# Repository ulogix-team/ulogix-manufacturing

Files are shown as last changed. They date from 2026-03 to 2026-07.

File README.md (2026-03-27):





<p align="center">
  
</p>

<p align="center">
  
  &nbsp;
  
  &nbsp;
  
  &nbsp;
  
  &nbsp;
  
</p>

# ulogix-manufacturing

Repositorio de ingeniería de proceso, diseño de planta, gemelo digital y automatización de la línea de bebidas FEMSA / Coca-Cola Fontibón.  
Cubre los módulos: **Introducción a la Automatización**, **Celda Robotizada**, **Digital Factory** y **Controladores Industriales**.



## Estructura

```
ulogix-manufacturing/
├── proceso/          DOP, DAP, P&ID, ISA-95, recetas (Líneas 2, 3, 7)
├── planta/           Layout funcional FEMSA, planos 2D, flujo de materiales
├── gemelo-digital/   Digital Factory NX MCD, señales I/O, conexión Logix Emulate
├── nx/               Siemens NX: modelos 3D, exportación RobotStudio→NX
├── studio-5000/      Studio 5000 / Logix Emulate: programas .ACD, tags
├── grafcet/          Control secuencial Grafcet por producto y modo
├── robotstudio/      Celda ABB, simulación, RAPID, análisis de riesgos ISO 10218
└── documentos/       Documentación técnica general y taller de módulo
```



## Líneas de Producción — FEMSA / Coca-Cola Fontibón

| Línea | Producto | Envase | Volumen | Maquinaria principal |
|---|---|---|---|---|
| **Línea 1** | Bebida carbonatada | Vidrio retornable | 330 mL | KRONES Lavatec · HEUFT SX-prewash · KRONES Modulfill HES |
| **Línea 2** | Bebida carbonatada | PET no retornable | 1.5 L | KRONES Contiform Bloc · HEUFT PRIME |
| **Línea 3** | Agua purificada | Garrafón retornable | 25 L | KRONES Hydronomic · HEUFT PRIME |

> Cada producto difiere en envase, velocidad, secuencia Grafcet, inspección y receta — cumpliendo C1 del proyecto integrador.



## Tareas por Módulo

<table>
<tr>
  <td align="center"></td>
  <td>
    <strong>proceso/</strong> — Módulo 1 (Intro Automatización)<br/>
    • Definir arquitectura ISA-95 (Mar 14) — A. Morales<br/>
    • Diagramas P&ID e identificación de sensores/actuadores (Mar 17) — A. Morales<br/>
    • Descripción detallada del proceso productivo (Mar 17) — J. Garzón<br/>
    • Parámetros de proceso y recetas por producto (Mar 18) — J. Díaz / J. Garzón<br/>
    <em>DOP/DAP: L2 (6op+5transp+2insp), L3 (6op+4transp+3insp), L7 (4op+4transp+3insp)</em>
  </td>
</tr>
<tr>
  <td align="center"></td>
  <td>
    <strong>planta/</strong> — Layout funcional<br/>
    • Layout dibujado: J.M. Beltrán (10/03/2026) · Revisado: J.J. Díaz · Aprobado: A.M. Morales<br/>
    • 3 líneas principales + área de jarabes + tratamiento de agua + almacenamiento<br/>
    • L2 y L3 vinculadas al corredor productivo común; L7 con espacio de maniobra para garrafones
  </td>
</tr>
<tr>
  <td align="center"></td>
  <td>
    <strong>robotstudio/</strong> — Módulo 4 (Celda Robotizada)<br/>
    • Justificación y selección del robot industrial (Mar 21) — A. Quenan<br/>
    • Diseño técnico de la celda (Mar 23) — A. Quenan / J. Beltrán<br/>
    • Análisis de riesgos ISO 10218 (Mar 24) — A. Quenan<br/>
    • Simulación en RobotStudio (Apr 11) — A. Quenan<br/>
    • Exportar puntos RS→NX (Apr 18) — A. Quenan / J. Beltrán <em>(sup: S. Sanchez)</em>
  </td>
</tr>
<tr>
  <td align="center"></td>
  <td>
    <strong>nx/</strong> — Módulos 4–5<br/>
    • Modelado 3D de la línea en NX (Mar 25) — J. Beltrán <em>(sup: S. Sanchez)</em><br/>
    • Exportar puntos de RobotStudio a NX (Apr 18) — J. Beltrán <em>(sup: S. Sanchez)</em>
  </td>
</tr>
<tr>
  <td align="center"></td>
  <td>
    <strong>gemelo-digital/</strong> — Módulo 5 (Digital Factory)<br/>
    • Configuración del entorno Digital Factory (Apr 18) — J. Beltrán <em>(sup: S. Sanchez)</em><br/>
    • Virtualización de actuadores y sensores (Apr 22) — A. Morales / J. Beltrán <em>(sup: S. Sanchez)</em><br/>
    • Conexión Logix Emulate – Modelo 3D (Apr 25) — J. Díaz / J. Beltrán <em>(sup: S. Sanchez)</em>
  </td>
</tr>
<tr>
  <td align="center"></td>
  <td>
    <strong>grafcet/ + studio-5000/</strong> — Módulos 4 y 6 (Controladores)<br/>
    • Diseño del Grafcet de control secuencial, por producto y modo (Mar 25) — J. Díaz<br/>
    • Implementación Ladder en Logix Emulate (Apr 22) — J. Díaz<br/>
    • Validación funcional PLC – Gemelo Digital (Apr 29) — J. Díaz / J. Beltrán
  </td>
</tr>
</table>



## Responsables y Supervisiones

| Módulo | Responsable | GitHub | Supervisor de par |
|---|---|:---:|---|
| NX / Digital Factory | Juan Manuel Beltrán Botello | [@JuanBeltran2024](https://github.com/JuanBeltran2024) | **Samuel D. Sanchez** |
| RobotStudio / Celda | Andrés Felipe Quenan Pozo | [@Andres-Felipe-Quenan](https://github.com/Andres-Felipe-Quenan) | Andrés M. Morales |
| Arquitectura ISA-95 / P&ID | Andrés Mauricio Morales Martínez | [@mora200217](https://github.com/mora200217) | Andrés F. Quenan |
| PLC / Grafcet / Ladder | Juan José Díaz Guerrero | [@Judiazgu](https://github.com/Judiazgu) | Juan F. Triana |
| Proceso / VSM / Recetas | Jorge Nicolas Garzón Acevedo | [@Nicolas-Eule](https://github.com/Nicolas-Eule) | Juan M. Beltrán |

**Supervisores académicos:** Carlos J. Cortés · Luis M. Méndez · Víctor H. Grisales · Ricardo Ramírez · Ubaldo García · Eduardo Barrera



## Flujo de Trabajo

```
main ──────────────────► producción estable
  └── develop ─────────► integración y desarrollo
```



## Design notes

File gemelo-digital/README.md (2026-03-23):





# gemelo-digital — Digital Factory



Modelado del gemelo digital con integración de sensores, actuadores virtuales y conexión con Logix Emulate (Módulo 5 — Digital Factory).

## Contenido esperado

- `modelos/` — Archivos de simulación Digital Factory / NX MCD
- `sensores-actuadores/` — Configuración de señales I/O virtuales, mapeo con PLC

## Responsables

| Rol | Nombre | GitHub |
|---|---|:---:|
| Desarrollador principal | Juan Manuel Beltrán Botello | [@JuanBeltran2024](https://github.com/JuanBeltran2024) |
| Integración ISA-95 / Red | Andrés Mauricio Morales Martínez | [@mora200217](https://github.com/mora200217) |
| **Supervisor NX/DF** | **Samuel David Sanchez Cardenas** | [@samsanchezcar](https://github.com/samsanchezcar) |



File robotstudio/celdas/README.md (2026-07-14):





# Sistema Gantry Cartesiano XZ


Esta celda automatiza el paletizado alternado de dos productos distintos —cajones de botellas retornables de 330 ml y paquetes termoformados PET de 1.5 L— mediante un sistema gantry de diseño propio, con dos ejes cartesianos: un eje X de 5 m sobre perfil Bosch Rexroth de correa dentada (motor ABB MU 200 + reductor planetario Apex Dynamics 5:1), y un eje Z de 2.3 m sobre husillo de bolas Bosch Rexroth 40x10 (motor ABB MU 300, acoplado directo sin reductor). Ambos ejes se controlan como ejes externos desde un controlador ABB IRC5, aprovechando motores ABB para mantener compatibilidad de programación con el resto de la línea.
El efector final es un gripper neumático de 4 mordazas (2 cilindros Festo DSBC-80-150 por mordaza), que sujeta cada capa completa de pallet por fricción lateral —hasta ~260 kg en el caso más pesado— y la traslada hasta uno de los dos pallets de destino según el tipo de producto detectado en la banda de infeed. El circuito neumático incluye válvulas de retención pilotada en cada cilindro para prevenir la caída de la carga ante una eventual pérdida de presión en tránsito.
La celda cuenta con vallado perimetral, puerta con enclavamiento, y cortinas de luz con muting en los dos puntos de interfaz con las bandas transportadoras (2 outfeed).

<p align="center">
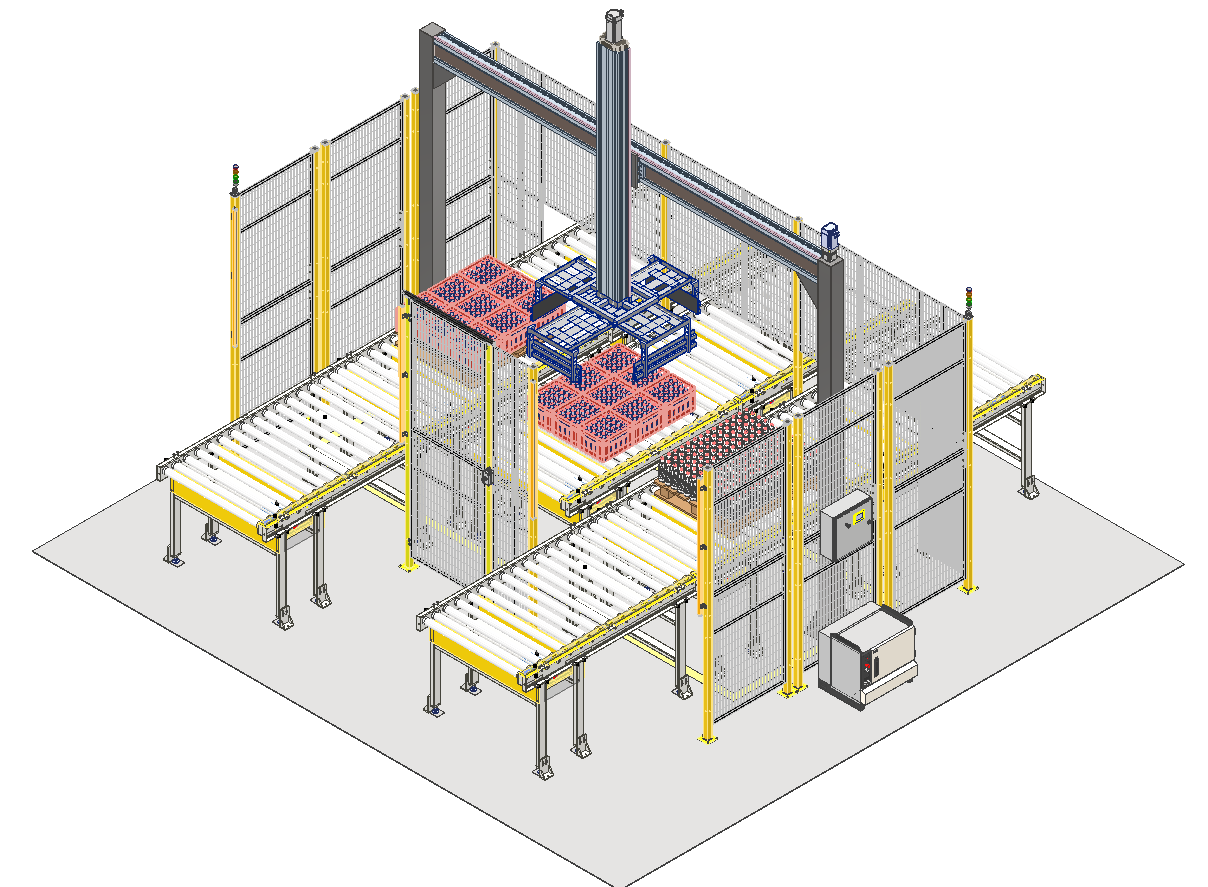
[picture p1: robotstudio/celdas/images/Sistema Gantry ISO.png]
Sistema Gantry
  
</p>

## Diseño

### 1. Función y proceso
Paletizado automático alternado de dos productos: capas de cajones retornables de 330 ml (9 cajones/capa, 6 capas/pallet) y capas de paquetes termoformados PET de 1.5 L (28 paquetes/capa, 5 capas/pallet). El sistema recibe el producto por una banda de infeed que alterna capa a capa entre ambos tipos, y lo distribuye hacia dos líneas de outfeed independientes según el producto detectado.
El archivo de modelado cad se encuentra disponible en [Celda1](cad/Celda1.zip)

### 2. Estructura mecánica y ejes de movimiento
| **Elemento** | **Especificación** |
|---|---|
| Configuración | Gantry cartesiano de 2 ejes (X horizontal, Z vertical), soportado sobre 2 pilares |
| Eje X | Perfil Bosch Rexroth de correa dentada, 5 m de recorrido |
| Motor eje X | ABB MU 200 + reductor planetario Apex Dynamics 5:1 |
| Eje Z | Husillo de bolas Bosch Rexroth 40x10, 2.3 m de recorrido |
| Motor eje Z | ABB MU 300, acoplado directo (sin reductor) |
| Controlador | ABB IRC5 (ejes gestionados como ejes externos) |
| Carga de diseño verificada | 300 kg sobre el eje Z — validado con margen (~46% en aceleración, ~58% en sostenimiento) bajo Trms del MU300 con *lead* de husillo de 10 mm |

### 3. Efector final (gripper)
- 4 mordazas neumáticas, accionamiento por fricción lateral sobre la capa de pallet
- 2 cilindros Festo DSBC-80-150-PPSA-N3 por mordaza (8 en total), diámetro dimensionado para el caso crítico (paquetes 1.5 L, ~260 kg, μ≈0.35 poliuretano-LDPE)
- Cuerpo del gripper: pieza manufacturada en aluminio 6061-T6

### 4. Sistema Neumático
| **Función** | **Componente** |
|---|---|
| Retención de carga ante pérdida de presión | 8x válvulas de retención pilotada Festo HGL-3/8 (una por cilindro) |
| Actuación direccional | Electroválvula Festo VUVS-L30 (5/2, doble solenoide) |
| Control de velocidad de cierre | Reguladores de caudal unidireccionales Festo GRLA-3/8 |
| Ajuste de fuerza de apriete por producto | Regulador de presión proporcional Festo VPPM-6L |
| Acondicionamiento de aire | FRL Festo MS4-LFR-1/4 |
| Retroalimentación de posición | Sensores magnéticos Festo SMT-8M-A (2 por mordaza) |

### 5. Transporte de material
- 8x bandas motorizadas Interroll PM 9710 (infeed + 2 líneas de outfeed)
- 3x sensores fotoeléctricos retroreflectivos con filtro de polarización Pepperl+Fuchs OBR7500, para detección confiable de cajones y envoltura PET transparente (1 infeed, 2 outfeed)

### 6. Sistema eléctrico
| **Función** | **Componente** |
|---|---|
| Alimentación IRC5 (motores MU200/MU300) | Breaker ABB S203-K25 + RCD tipo B ABB F204B |
| Circuito de control 24VDC | Fuente ABB CP-E 24/10.0 |
| Cargas individuales de 24VDC (HMI, interlock, cortinas, torres) | Mini-breakers ABB S201-C1 |
| Gabinete | Schneider NSYCRN75250, IP66 |
| Interfaz operador | HMI ABB CP620 |

### 7. Seguridad
- Vallado perimetral modular Satech ImpactGuard (malla 20×100 mm, absorción de impacto 2200 J)
- Puerta de acceso con enclavamiento Schmersal AZM 415
- 2x cortinas de luz ReeR Admiral AD 1651 (Tipo 4 / PL e) con interfaz de muting SR ONE M, en infeed y outfeed
- 2x paros de emergencia (EAO Serie 45 en puerta, EAO Serie 84 Smart-Box en HMI)
- 2x torres de señalización Werma KS72
- Freno electromagnético integrado en el motor MU 300 (retención de posición vertical)

## Resumen de costos

**Total estimado: ~US$108,143**

| Categoría | Peso aproximado en el total |
|---|---|
| Transportadores (8x Interroll PM 9710) | ~41% — el ítem dominante en esta celda |
| Controlador + servomotores (IRC5 + MU300 + MU200) | ~21% |
| Estructura mecánica (ejes lineales Bosch Rexroth, perfiles, gripper manufacturado) | ~24% |
| Seguridad (vallado, cortinas, interlock, paros, torres) | ~5% |
| Sistema neumático (cilindros, válvulas, VPPM) | ~3% |
| Protecciones eléctricas, tablero y HMI | ~1% |

**Nivel de confianza**: bajo para IRC5+servomotores y ejes lineales Bosch Rexroth (configuración no estándar, sin precio público); medio para el gripper y estructura manufacturada (estimación de costo de material + maquinado). Alto para componentes de catálogo (Festo, ABB, sensores Pepperl+Fuchs).  

El BOM se encuentra disponible en [BOM1](BOM/BOM1.xlsx)

# Manipulador Articulado ABB IRB 5710


Esta celda automatiza el paletizado de garrafones de 25 litros de agua mediante un robot articulado de 6 ejes ABB IRB 5710 (variante 110 kg / 2.3 m de alcance), controlado por un OmniCore V250XT. El robot recibe los garrafones desde una banda transportadora de infeed y los deposita sobre un pallet con rack metálico, formando unidades de 5 capas × 6 posiciones.
El efector final es un gripper neumático de 3 ventosas tipo fuelle, cada una con su propio circuito de vacío independiente (generador Festo OVEM con válvula anti-retorno y sensor de vacío integrado), lo que permite levantar 3 garrafones por ciclo (~90 kg de carga total incluyendo el gripper) y detectar de forma individual si alguno de los tres no fue sujetado correctamente. El pallet completo se evacúa mediante un tramo de bandas motorizadas Interroll PM 9710.
La celda está delimitada por un perímetro de seguridad con vallado modular, puerta de acceso con enclavamiento, y cortinas de luz con función de muting en los puntos de infeed y outfeed, permitiendo el paso automático de material sin exponer al personal a la zona de riesgo del robot.

<p align="center">
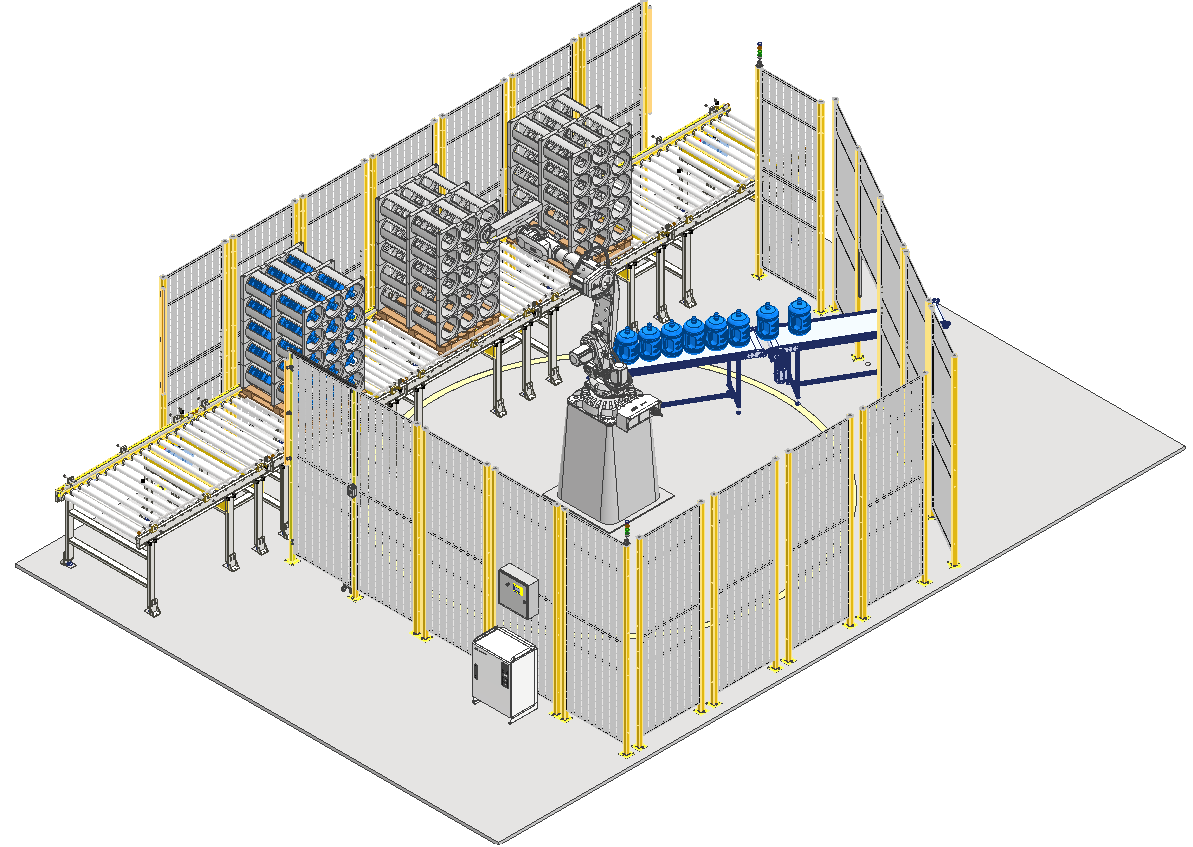
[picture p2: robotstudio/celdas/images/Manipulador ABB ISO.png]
Manipulador ABB
  
</p>

## Diseño

### 1. Función y proceso

Paletizado automático de garrafones de 25 litros de agua. El robot recibe los garrafones desde una banda transportadora de infeed y los deposita sobre un pallet con rack metálico, formando unidades de 5 capas × 6 posiciones. El robot manipula 3 garrafones por ciclo mediante un gripper de vacío de 3 ventosas.
El archivo de modelado cad se encuentra disponible en [Celda2](cad/Celda2.7z)

### 2. Estructura mecánica

| Elemento | Especificación |
|---|---|
| Robot | ABB IRB 5710-110/2.3 (110 kg de carga, 2.3 m de alcance) |
| Controlador | ABB OmniCore V250XT |
| Software de programación | RobotStudio, RobotWare 7.2 |
| Carga manipulada por ciclo | 3 garrafones + gripper ≈ 90 kg (dentro de la capacidad de 110 kg del robot) |
| Configuración de pallet | 5 capas × 6 posiciones sobre rack metálico |

### 3. Efector final (gripper)

- 3 ventosas neumáticas tipo fuelle (2.5 pliegues), diámetro ~180-200 mm
- Punto de contacto: tapa y hombro del garrafón, hasta casi el cuerpo (~270 mm de diámetro disponible)
- Nivel de vacío de trabajo objetivo: -0.30 bar (dimensionado para minimizar tiempo de ciclo con la superficie de contacto disponible)
- 3 circuitos de vacío completamente independientes (uno por ventosa), para detección individual de fallo de sujeción por garrafón

### 4. Sistema neumático (circuito de vacío)

| Función | Componente | Cantidad |
|---|---|---|
| Generación de vacío (alto caudal, válvula y sensor integrados) | Festo OVEM-14-L-B-QO-CE-N-1P | 3 (uno por ventosa) |
| Filtro de vacío (cuerpo transparente, inspección visual) | Festo VAF-PK-6 | 3 |
| Acumulador de vacío (punto de uso, liviano para no afectar el payload) | Festo CRVZS-0.1 (combinable en paralelo si se requiere más volumen) | 3 |
| Acondicionamiento de aire de entrada | Festo MS4-LFR-1/4-D6-C-P-M-AG-BAR-B | 1 (centralizado) |

### 5. Transporte de material

- 5x bandas motorizadas Interroll PM 9710 en la salida de pallets (outfeed), capacidad muy por encima de la carga real (~800-850 kg por pallet)

### 6. Sistema eléctrico

| Circuito | Protección |
|---|---|
| Alimentación OmniCore V250XT (robot + drives) | Breaker ABB S203-K32 (3×32 A) + RCD tipo B ABB F204B |
| Circuito de control 24VDC | Fuente ABB CP-E 24/10.0 |
| Cargas individuales de 24VDC (HMI, puerta, torres, cortinas/interfaces) | 7x mini-breakers ABB S201-C1 |
| Gabinete | Schneider NSYCRN75250, IP66 |
| Interfaz operador | HMI ABB CP620 |

### 7. Seguridad

- Vallado perimetral modular Satech ImpactGuard (malla 20×100 mm, absorción de impacto 2200 J), radio de riesgo calculado a partir del alcance del robot (2.3 m) + gripper + garrafón en la postura más desfavorable
- Puerta de acceso con enclavamiento Schmersal AZM 415
- 2x cortinas de luz ReeR Admiral AD 1501 con interfaz de muting SR ONE M, en infeed y outfeed
- 1x cortina de control de acceso ReeR Admiral AD 2B con interfaz SR ONE (sin muting)
- 2x paros de emergencia (EAO Serie 45, 2NC, en puerta; EAO Serie 84 Smart-Box en HMI)
- 2x torres de señalización Werma KS72
- Avisos de advertencia normalizados: tipo "peligro" en la puerta de acceso, tipo "atención" en las zonas de muting

## Resumen de costos

**Total estimado: ~US$132,046**

| Categoría | Peso aproximado en el total |
|---|---|
| Robot + controlador (IRB 5710 + OmniCore V250XT) | ~66% del total — el ítem dominante |
| Transportadores (5x Interroll PM 9710) | ~21% |
| Gripper + sistema neumático de vacío | ~4% |
| Seguridad (vallado, cortinas, interlock, paros, torres) | ~4% |
| Protecciones eléctricas y tablero | ~1% |
| HMI y otros | ~1% |

**Nivel de confianza**: bajo para robot, controlador y transportadores (ABB e Interroll no publican precio, se cotiza por proyecto — estimado con base en rangos de mercado comparables). Alto para componentes de catálogo estándar (Festo, ABB protecciones, ReeR, EAO, Werma).

El BOM se encuentra disponible en [BOM2](BOM/BOM2.xlsx)



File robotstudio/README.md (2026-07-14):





# Justificación



El análisis de los mapas de flujo de valor (Value Stream Mapping, VSM) permitió identificar que la operación de paletizado constituye el principal cuello de botella en las tres líneas de producción de la planta. Esta etapa presenta los mayores tiempos de ciclo y los menores niveles de disponibilidad respecto a las demás operaciones, ocasionando acumulación de producto antes del final de la línea, incremento del trabajo en proceso y pérdidas de productividad asociadas a tiempos de espera.  
Debido a que el proceso de paletizado se realiza de manera manual, su capacidad depende directamente del desempeño del operario, siendo susceptible a variaciones ocasionadas por fatiga, pausas operativas, diferencias en el ritmo de trabajo y limitaciones ergonómicas propias de la manipulación repetitiva de cargas. Como consecuencia, la velocidad de evacuación del producto terminado resulta inferior a la capacidad de producción de las etapas anteriores, generando saturación en la entrada del paletizado y reduciendo la continuidad del flujo productivo.

# Propuesta



Con el propósito de eliminar esta restricción de capacidad, se propone la implementación de celdas robotizadas de paletizado. La solución contempla una celda compartida para las líneas 1 y 2, debido a que ambas poseen altas velocidades de producción y características similares de empaque, y una segunda celda dedicada para la línea 3, correspondiente al proceso de garrafones, cuyas dimensiones, peso y configuración de carga requieren una solución específica.

La incorporación de manipuladores industriales permite ejecutar el proceso de paletizado con tiempos de ciclo constantes, alta repetibilidad y operación continua, eliminando las variaciones inherentes al proceso manual. De esta manera, la capacidad del sistema de paletizado supera la demanda de producción de las líneas, evitando la acumulación de producto previo a esta estación y permitiendo mantener un flujo continuo hasta el despacho del producto terminado.

# Celdas de paletizado



Las celdas de paletizado se diseñaron teniendo en cuenta factores como tipo de producto, tipo de empaque (encajonado, termoformado, racks), disposición del producto en el pallet, carga por ciclo y tiempo para producir la cantidad de unidades que se operan en un ciclo. Los diseños fueron elegidos para optimizar la etapa de paletizado y mejorar su eficiencia reduciendo los tiempos de ciclo.

## Línea 1 y Línea 2
La organización en los pallets es similar en los dos productos:  
En la línea 1 de botellas retornables de 330 ml los pallets están conformados por 6 capas de 9 cajones organizados en una matriz 3x3 con 30 botellas en cada uno.  
En la línea 2 de botellas PET de 1.5 l los pallets están conformados por 5 capas de 28 paquetes termoformados organizados en una matriz 7x4 con 6 botellas cada uno.  
De acuerdo a referencias de celdas robóticas de paletizado existentes. La duración de un ciclo (tiempo que tarda el mecanismo en tomar la carga llevarla a su destino y devolverse para tomar una nueva carga) es de aproximadamente entre 10 y 15 segundos, considerando que el tacktime de la línea 1 es de 0.1 segundos, al mover 3 cajones por ciclo (90 botellas) se encuentra un tiempo disponible de 9 segundos que resulta insuficiente para la operación, por lo tanto, se optó por mover una capa de pallet en cada ciclo (270 botellas) con un tiempo disponible de 27 segundos, suficiente para realizar el ciclo de forma segura. Por otro lado para mantener el mecanismo de sujeción compatible en dimensiones con el producto de la línea 2 (tacktime de 0.252 segundos) se optó tambíen por mover una capa de pallet (168 botellas) que resulta en un tiempo disponible por ciclo de 42.2 segundos.  
La organización de las capas en los pallets se hace de forma vertical y el transporte entre bandas las capas se hace de forma horizontal, por lo tanto, es necesario un sistema robótico tipo gantry que realice el paletizado de los dos productos y resulta suficiente un mecanismo de 2 ejes para relizar los ciclos de movimiento.

## Línea 3
En la línea 3 de garrafones de 25 l los pallets están conformados por 5 capas de racks organizados en una matriz 3x2, es decir, 6 garrafones en cada capa.  
Considerando un tacktime de 5 segundos, al mover en cada ciclo 3 unidades se tiene un tiempo disponible de 15 segundos, suficiente para un ciclo de operación, por otro lado, la organización del producto en los racks se realiza de forma lateral y la sujeción de forma vertical, es necesario un manipulador de 6 ejes para total libertad de movimiento en la organización del pallet.

## Contenido

- `celdas/` — Diseño de la celda: layout, alcance, seguridad, periféricos
- `programas-rapid/` — Código RAPID de las rutinas del robot
- `analisis-riesgos/` — Evaluación de riesgos y medidas de mitigación (ISO 10218)

## Responsable

Andrés Felipe Quenan Pozo · [@Andres-Felipe-Quenan](https://github.com/Andres-Felipe-Quenan)



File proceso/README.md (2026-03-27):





# proceso — Análisis del Proceso Productivo



Análisis del proceso de fabricación y despacho en la planta de bebidas FEMSA / Coca-Cola Fontibón, desde la recepción de insumos hasta el empaque y despacho. Desarrollado en el marco del **Módulo 1 — Introducción a la Automatización** del curso APM 2026-1.

## Líneas de Producción

| Línea | Producto | Envase | Volumen | Criterio de diferenciación |
|---|---|---|---|---|
| **Línea 1** | Bebida carbonatada | Vidrio retornable | 330 mL | Recepción retornable, lavado, saneamiento, inspección botella vacía (HEUFT SPECTRUM II SX-prewash), etiquetado, llenado (KRONES Modulfill HES), tapado |
| **Línea 2** | Bebida volumen medio | PET no retornable | 1.5 L | Cambio de familia de envase, soplado integrado (KRONES Contiform Bloc), llenado-cierre-etiquetado con diferencias en capacidad vs. línea retornable |
| **Línea 3** | Agua purificada | Garrafón retornable | 25 L | Gran volumen individual, tratamiento agua (KRONES Hydronomic), mayor exigencia sanitaria, tiempos unitarios mayores, logística diferenciada |

> Los tres productos cumplen el criterio C1 del proyecto integrador: diferencias en envase/geometría, velocidad de producción, secuencia lógica, inspección y recetas.



## Maquinaria de Referencia (Benchmark Industrial)

| Equipo | Fabricante | Función | Línea |
|---|---|---|---|
| Lavatec D / LavaClassic D | KRONES | Lavado de botellas retornables | L1 |
| HEUFT SPECTRUM II SX-prewash | HEUFT | Inspección y rechazo de retornables defectuosos antes del llenado | L1 |
| Modulfill HES | KRONES | Llenado higiénico bebidas carbonatadas en vidrio | L2 |
| Contiform Bloc | KRONES | Soplado + llenado integrado para envases PET hasta 3.5 L | L2 |
| Hydronomic | KRONES | Tratamiento y preparación de agua de proceso | L3 |
| HEUFT PRIME | HEUFT | Inspección envases llenos (fisicoquímica en línea) | L1, L2, L3 |

> Estas referencias se usan como benchmark técnico, no como confirmación del inventario exacto de la planta FEMSA visitada.



## DTP — Diagrama de Transformación de Producto

### Línea 1 — Vidrio retornable 330 mL

<p align="center">
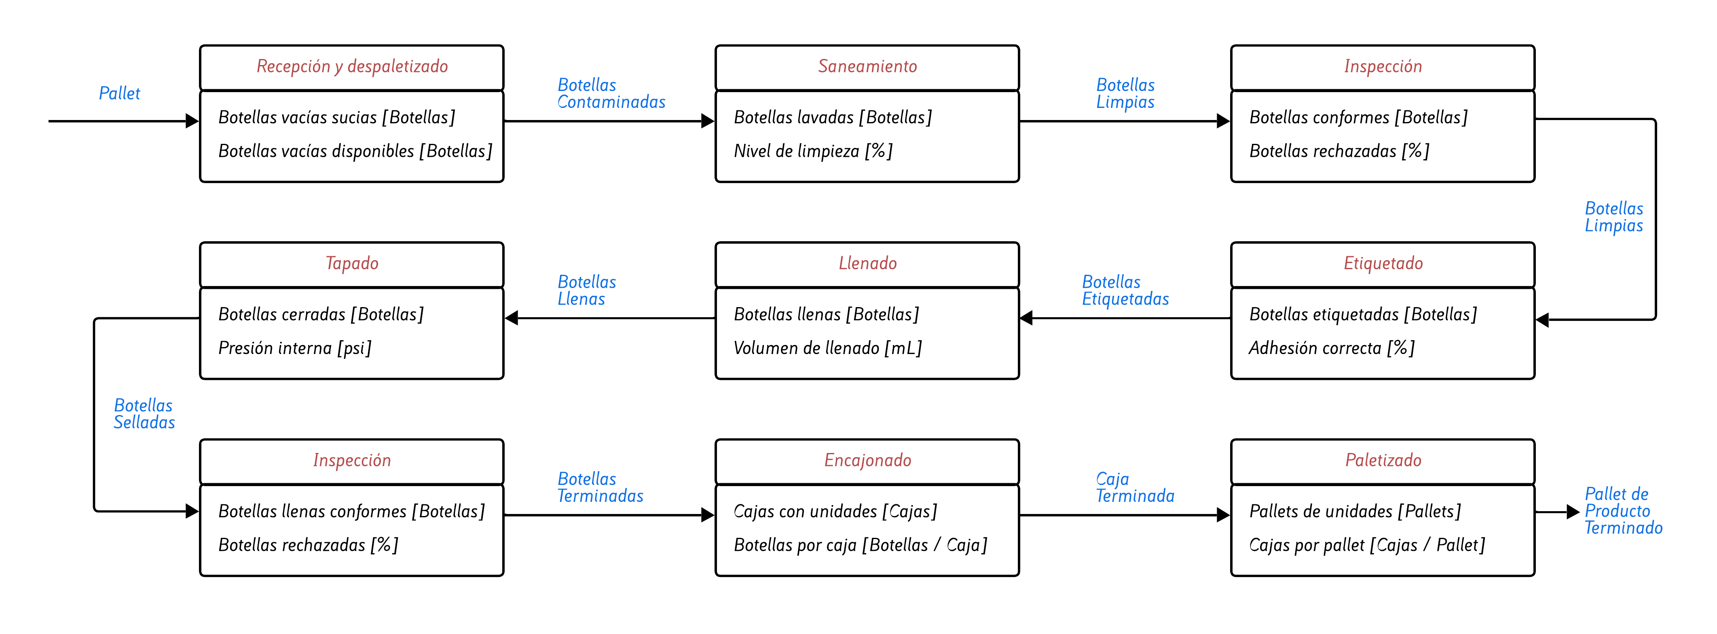
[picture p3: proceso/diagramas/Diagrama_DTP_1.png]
DTP_Linea_1
  
</p>

### Línea 2 — PET 1.5 L

<p align="center">
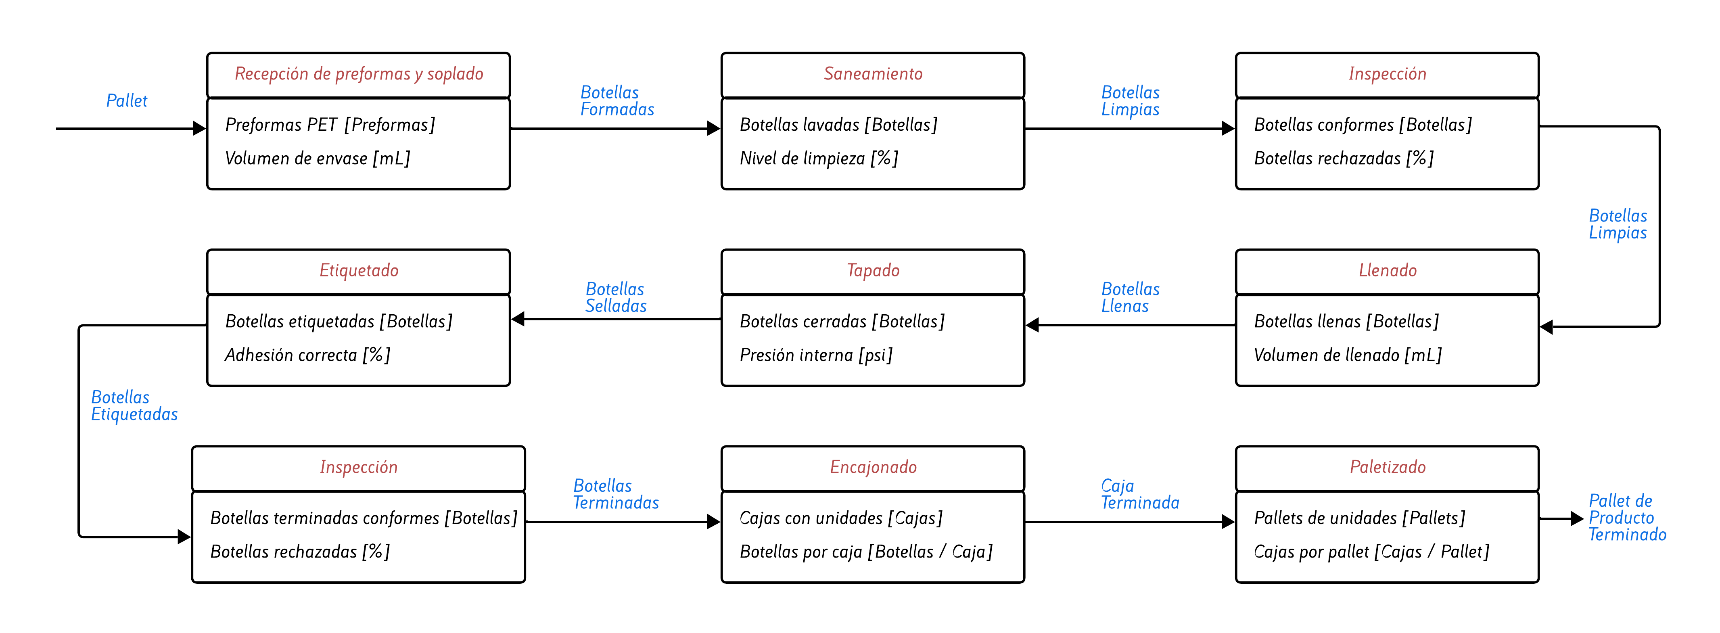
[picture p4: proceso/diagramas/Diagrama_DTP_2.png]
DTP_Linea_2
  
</p>

### Línea 3 — Garrafón 20 L

<p align="center">
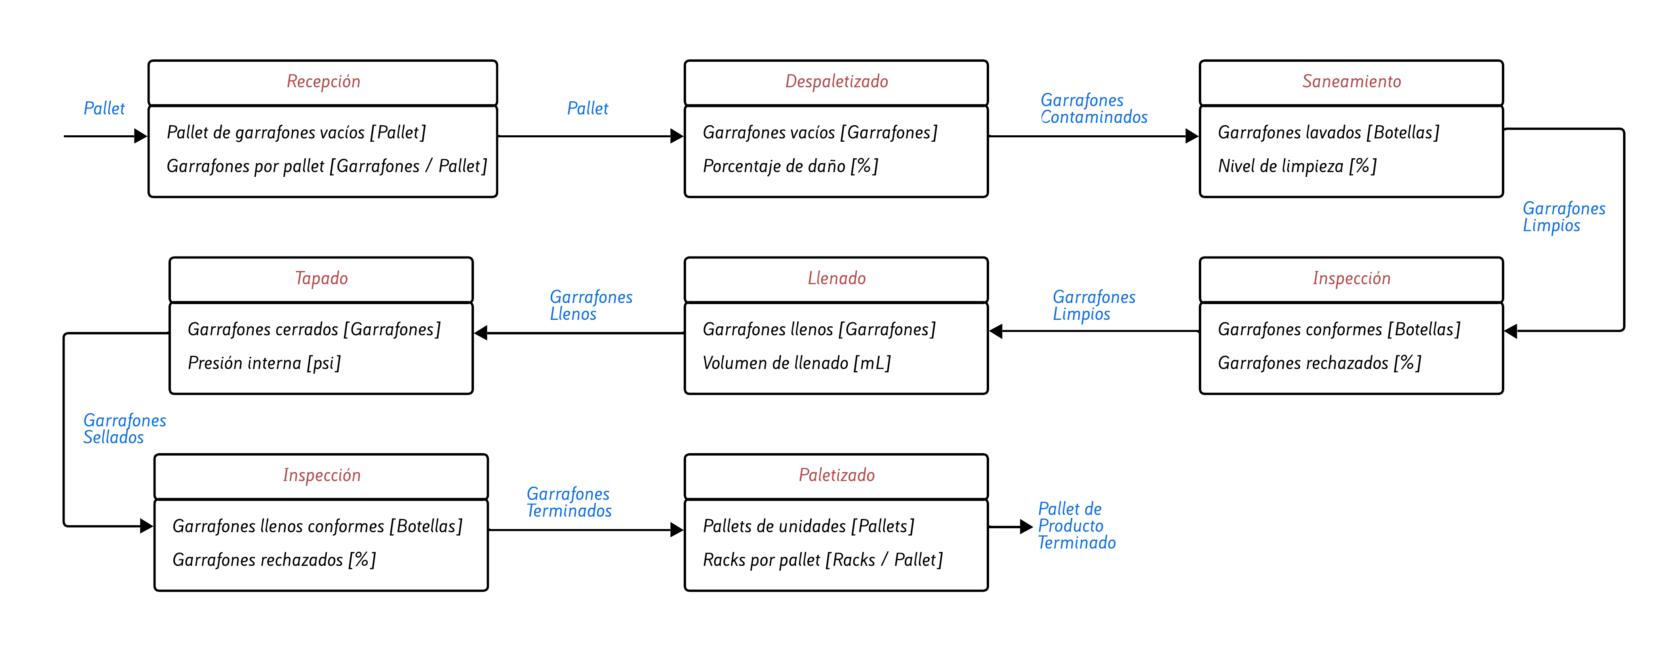
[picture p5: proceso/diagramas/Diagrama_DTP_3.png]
DTP_Linea_3
  
</p>

Los diagramas de transformación evidencian que las variables críticas del proceso se concentran en saneamiento (nivel de limpieza), llenado (volumen en mL), tapado (presión interna) y etiquetado (adhesión). Estas variables influyen directamente en la calidad del producto final, pero también en la velocidad de producción, ya que requieren control preciso y pueden generar rechazos. Se identifica que el llenado es una etapa sensible debido a la necesidad de mantener exactitud volumétrica y presión adecuada en bebidas gaseosas, lo cual puede reducir la disponibilidad efectiva del equipo por ajustes o mantenimiento. Asimismo, el proceso final de encajonado y paletizado representa una transformación logística que impacta significativamente el throughput total de la línea, especialmente al realizarse manualmente.

## DOP — Diagrama de Operaciones de Proceso

### Línea 1 — Vidrio retornable 330 mL

<p align="center">
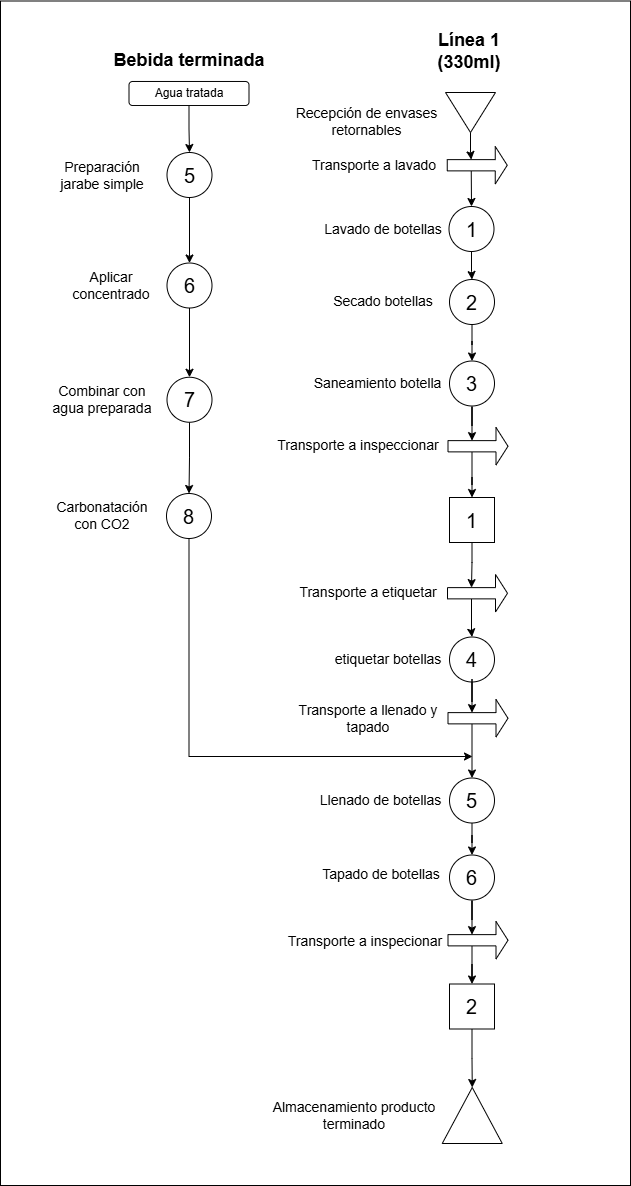
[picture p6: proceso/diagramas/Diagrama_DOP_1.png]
DOP_Linea_1
  
</p>

### Línea 2 — PET 1.5 L

<p align="center">
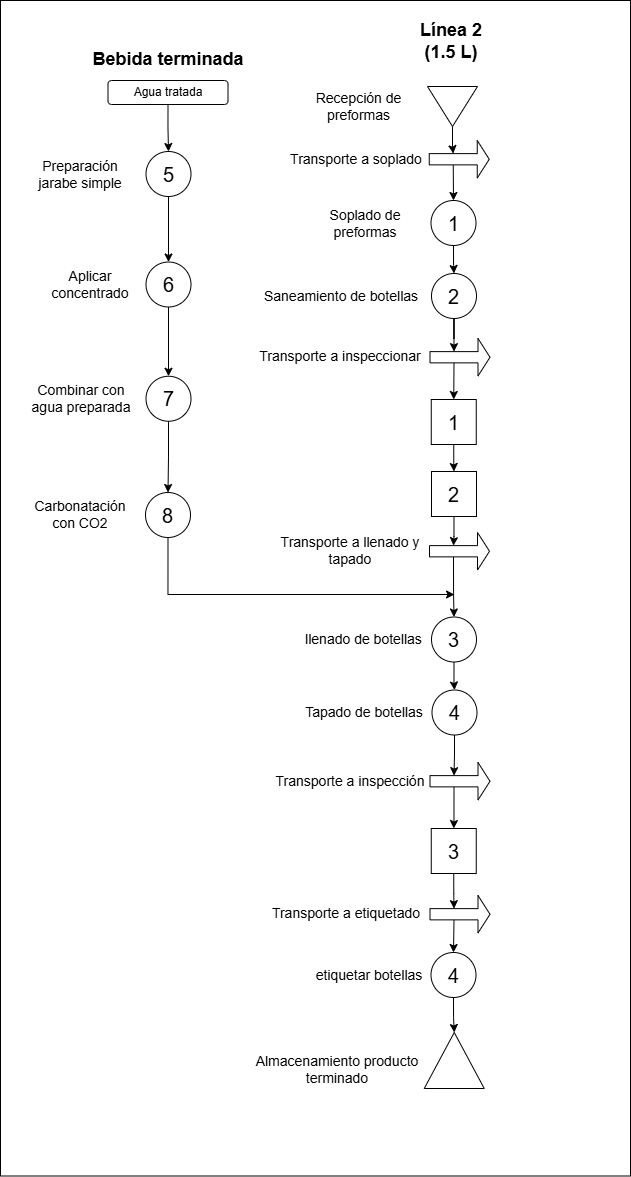
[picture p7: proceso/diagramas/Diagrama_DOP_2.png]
DOP_Linea_2
  
</p>

### Línea 3 — Garrafón 20 L

<p align="center">
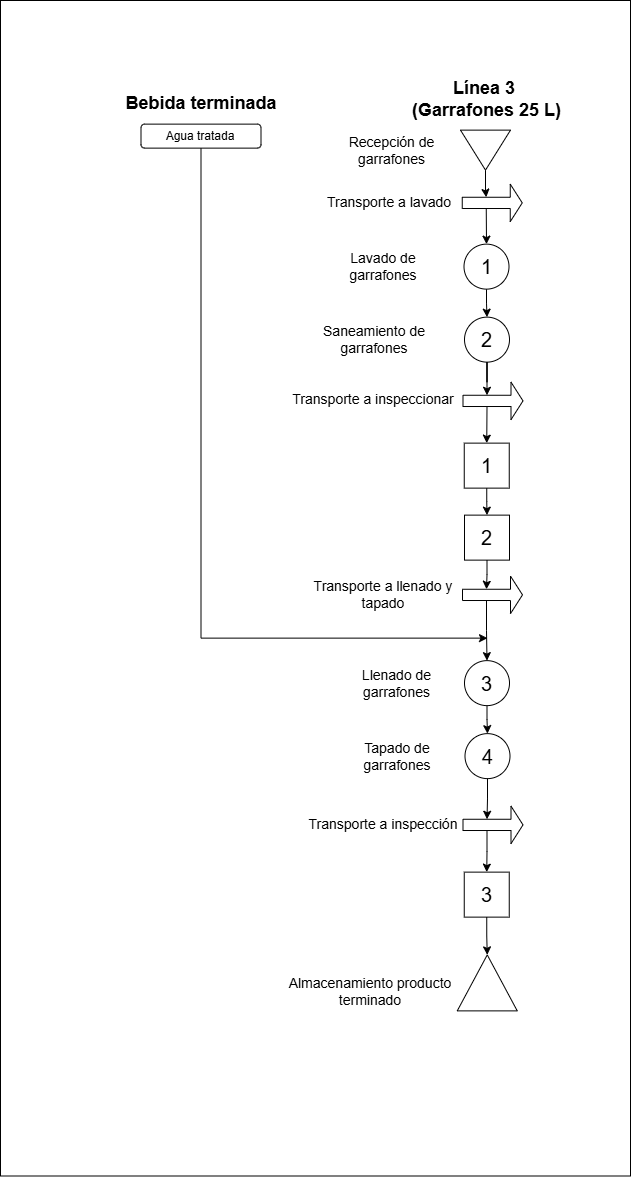
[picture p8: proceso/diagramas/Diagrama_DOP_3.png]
DOP_Linea_3
  
</p>

Los diagramas de operaciones de proceso muestran una secuencia lineal de operaciones con múltiples etapas de transporte entre procesos de lavado, saneamiento, inspección, llenado y tapado. El almacenamiento final sugiere que la capacidad de salida del sistema puede verse limitada por operaciones posteriores, lo cual es consistente con la necesidad de mejorar la automatización en la etapa de manipulación del producto terminado.



## DAP — Diagrama de Análisis de Proceso

### Línea 1 — Vidrio retornable 330 mL

<p align="center">
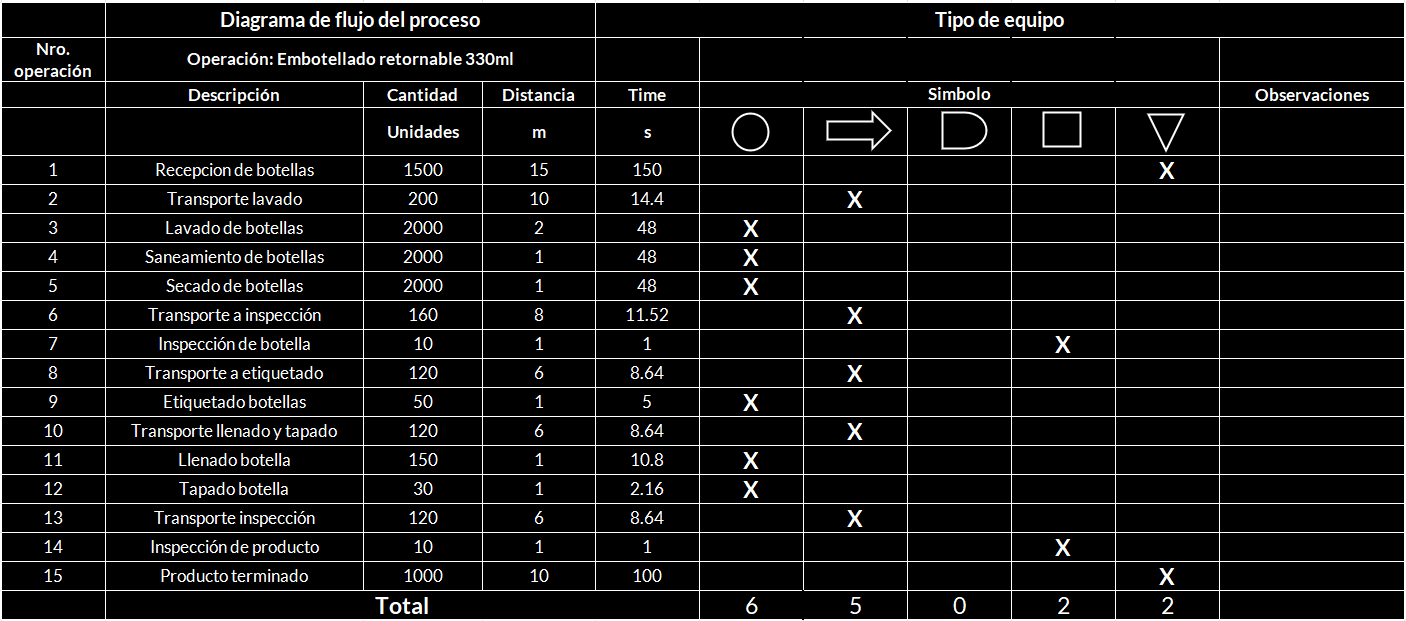
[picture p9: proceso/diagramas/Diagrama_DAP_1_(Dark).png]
DAP_Linea_1
  
</p>

### Línea 2 — PET 1.5 L

<p align="center">
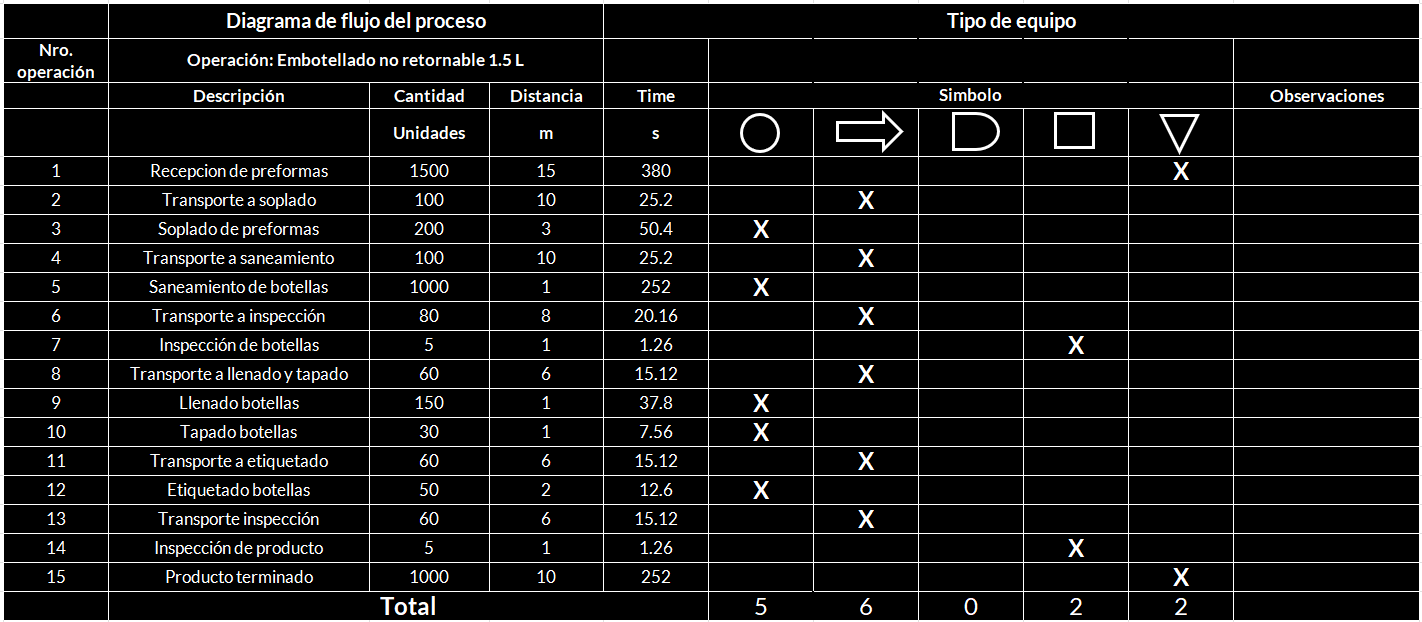
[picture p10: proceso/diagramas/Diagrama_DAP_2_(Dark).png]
DAP_Linea_2
  
</p>

### Línea 3 — Garrafón 20 L

<p align="center">
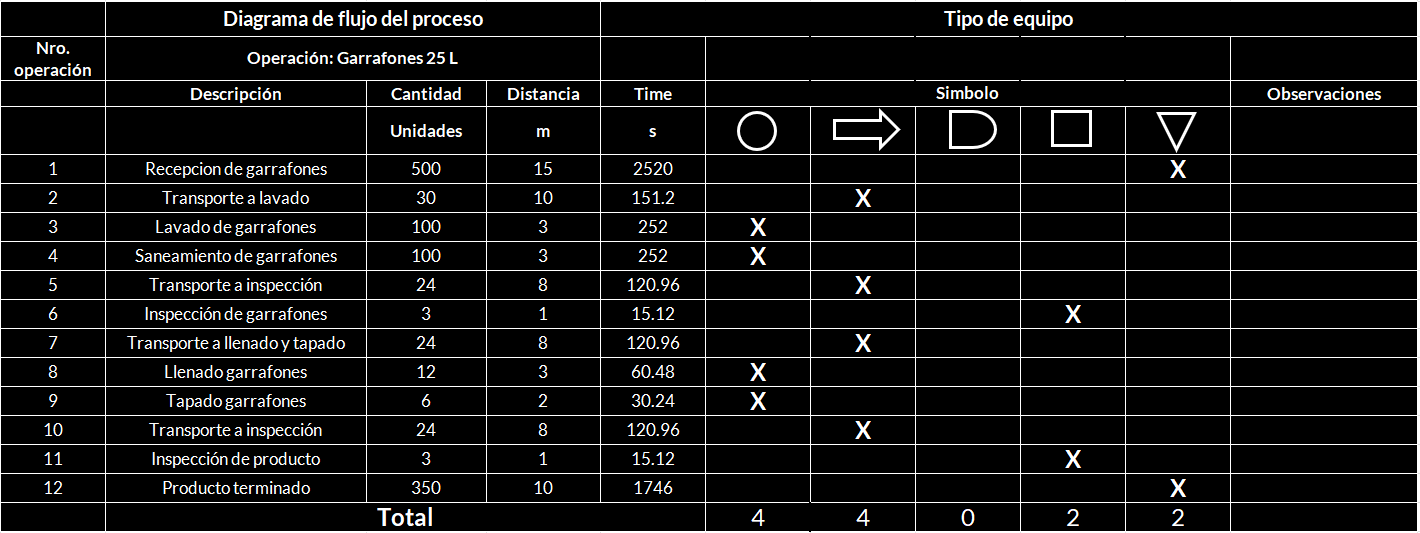
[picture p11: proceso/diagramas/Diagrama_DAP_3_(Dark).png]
DAP_Linea_3
  
</p>

### Resumen Diagrama de Análisis de Proceso
| Línea | Operaciones | Transportes | Demoras | Inspecciones | Almacenamientos | Total |
|---|---|---|---|---|---|---|
| Línea 1 — 330 mL retornable | 6 | 5 | 0 | 2 | 2 | **15** |
| Línea 2 — PET 1.5 L | 5 | 6 | 0 | 2 | 2 | **15** |
| Línea 3 — Garrafón 25 L | 4 | 4 | 0 | 2 | 2 | **12** |

Los diagramas de análisis de proceso evidencian que una proporción significativa de las actividades corresponde a transporte (6) e inspección (2), mientras que solo 5 corresponden a operaciones que agregan valor directo al producto. Esto indica un potencial de mejora en la reducción de movimientos innecesarios mediante mejor distribución de planta o automatización del manejo de materiales. El tiempo más alto se observa en saneamiento de botellas y en la recepción de preformas, mientras que el llenado presenta un tiempo considerable en relación con otras operaciones productivas. La presencia de múltiples transportes intermedios incrementa el lead time total del proceso y sugiere que la eficiencia global puede incrementarse mediante integración de equipos o automatización del flujo entre estaciones.



## VSM - Mapa de Flujo de Valor

### Línea 1 — Vidrio retornable 330 mL

<p align="center">
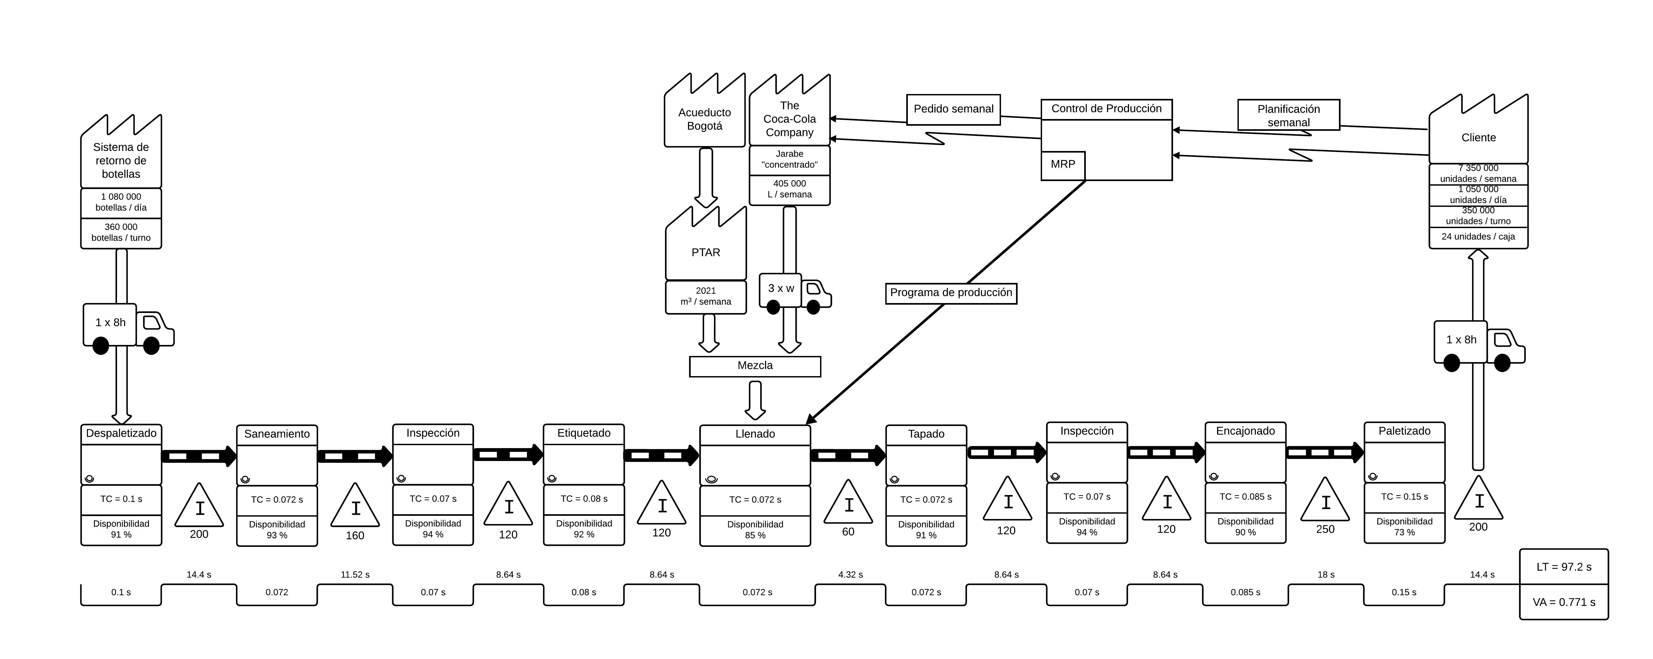
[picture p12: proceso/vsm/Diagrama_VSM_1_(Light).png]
VSM_Linea_1
  
</p>

### Línea 2 — PET 1.5 L

<p align="center">
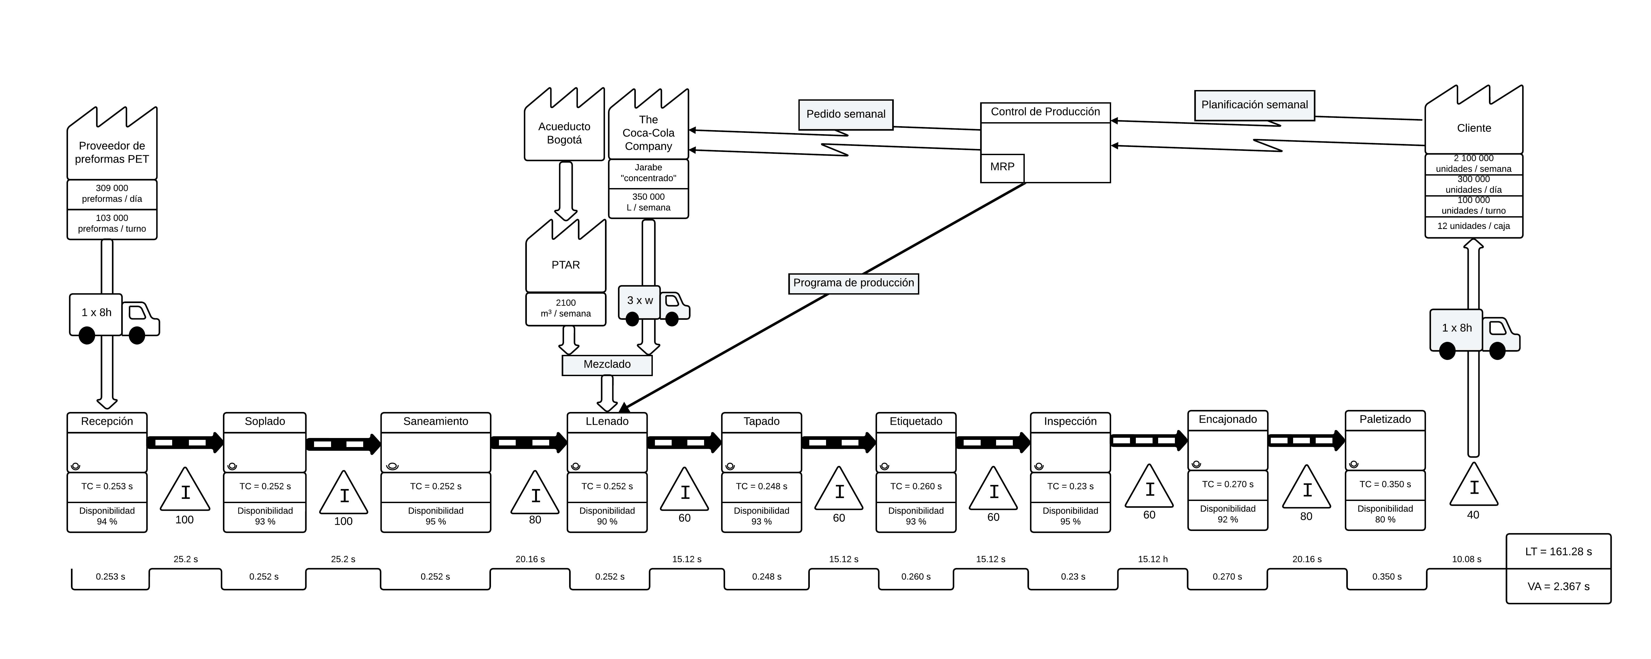
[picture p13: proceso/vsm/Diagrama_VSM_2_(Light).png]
VSM_Linea_2
  
</p>

### Línea 3 — Garrafón 20 L

<p align="center">
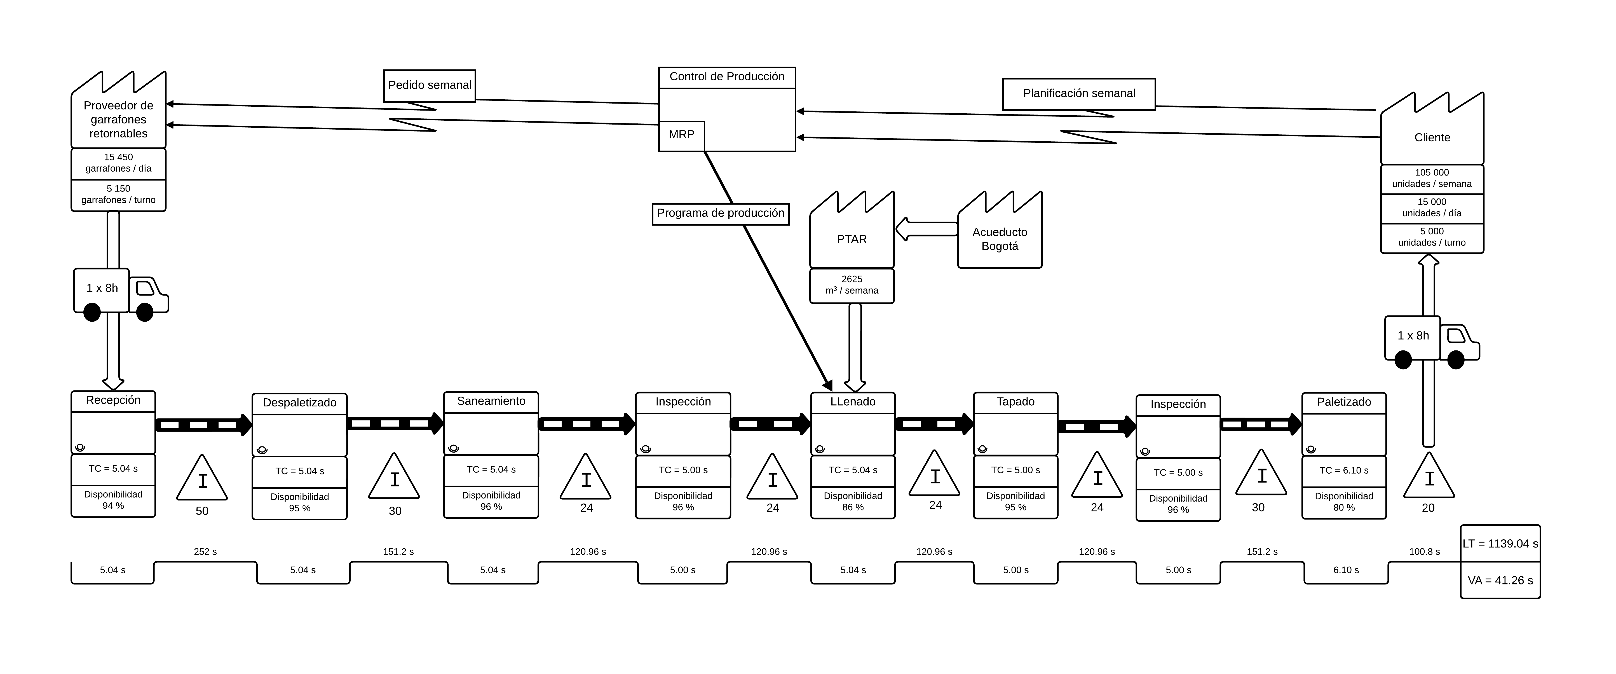
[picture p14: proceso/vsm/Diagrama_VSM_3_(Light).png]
VSM_Linea_3
  
</p>

Los diagramas VSM muestran que el tiempo total de proceso por ejemplo de la línea 1 (LT ≈ 97.2 s) es considerablemente mayor que el tiempo de valor agregado (VA ≈ 0.771 s), lo cual evidencia una alta proporción de tiempos de espera e inventario en proceso. Se identifica que el proceso de llenado tiene una disponibilidad relativamente menor (≈85%), lo que lo posiciona como un cuello de botella crítico debido a paradas por mantenimiento, ajustes de presión o control de volumen. Sin embargo, el mayor cuello de botella se encuentra en el paletizado, con una disponibilidad de aproximadamente 73% y un tiempo de ciclo significativamente mayor (0.15 s), asociado a la manipulación manual de cajas. Esto limita el flujo de salida de toda la línea, generando acumulación de inventario previo a esta estación. Una propuesta de automatización permitiría aumentar la disponibilidad, reducir variabilidad y mejorar la sincronización con el takt time requerido por la demanda.



## Arquitectura ISA-95

La línea de producción se estructura según los niveles ISA-95:

```
Nivel 4  ERP / MRP — planificación semanal (pedido semanal → MRP)
Nivel 3  MES — Power BI, OEE, analítica Python (S. Sanchez / J. Triana)
Nivel 2  SCADA Ignition — supervisión y control proceso (J. Triana)
Nivel 1  PLC Studio 5000 / Logix Emulate — control secuencial (J. Díaz)
Nivel 0  Sensores / Actuadores — líneas L1, L2, L3
```



## Contenido de esta Carpeta

- `diagramas/` — DTP, DOP, DAP, P&ID
- `vsm/` — VSM estado actual y futuro por línea (ver `ulogix-data-finance/simulacion/vsm/`)
- `recetas/` — Parámetros de proceso y recetas por producto (Líneas 1, 2 y 3)

## Responsables

| Rol | Nombre | GitHub |
|---|---|:---:|
| Proceso / VSM / Recetas | Jorge Nicolas Garzón Acevedo | [@Nicolas-Eule](https://github.com/Nicolas-Eule) |
| Arquitectura ISA-95 / P&ID | Andrés Mauricio Morales Martínez | [@mora200217](https://github.com/mora200217) |
| **Supervisor de par** | **Juan Manuel Beltrán Botello** | [@JuanBeltran2024](https://github.com/JuanBeltran2024) |



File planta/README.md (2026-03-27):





# planta — Diseño de Distribución en Planta



Diseño de la distribución física de la planta y planos de layout.

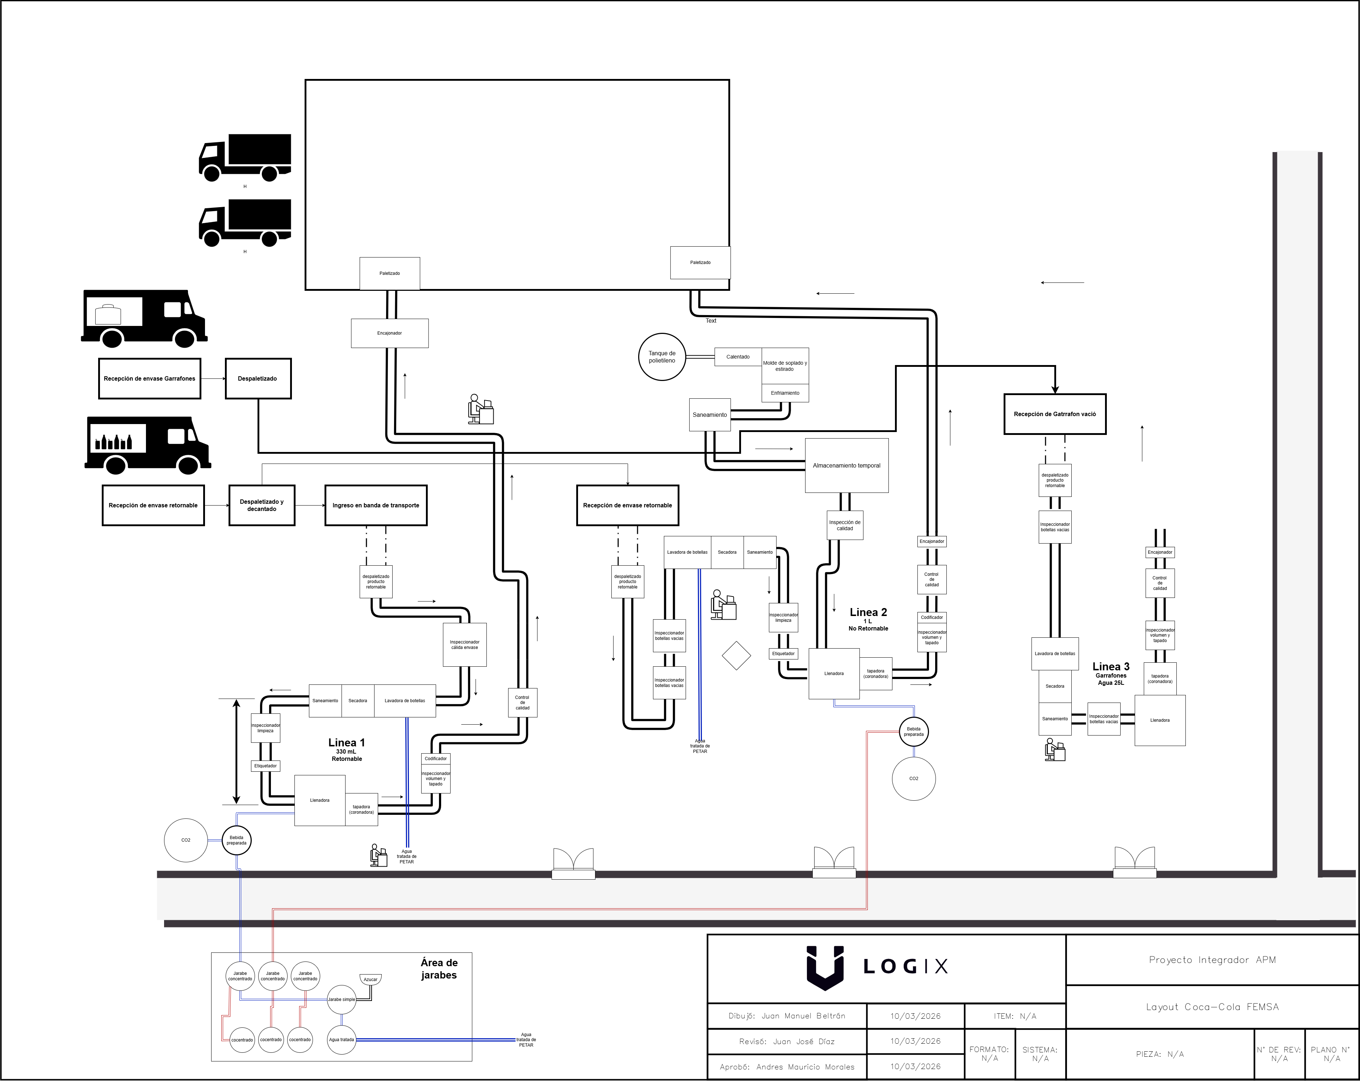
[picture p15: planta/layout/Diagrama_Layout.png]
Diagrama de Layout


El layout muestra una distribución funcional de tres líneas de producción (retornable, no retornable y garrafones 25 L) que convergen en áreas comunes como jarabes, tratamiento de agua y almacenamiento temporal. Se observa una alta dependencia de sistemas de transporte entre estaciones, lo cual incrementa tiempos no productivos y acumulación de inventario intermedio. En particular, el flujo hacia  el área de paletizado presenta trayectorias largas y posibles cruces de flujo que pueden generar congestión operativa. Además, el paletizado manual implica intervención humana en una etapa de alto volumen, lo que limita la capacidad de producción y genera variabilidad en el tiempo de ciclo. Esto sugiere una oportunidad clara de mejora mediante un proceso de automatización y optimización de rutas de transporte interno.

## Contenido esperado

- `layout/` — Planos 2D de distribución (Draw.io / AutoCAD / NX)
- `calculos/` — Cálculos de dimensionamiento, áreas y flujos de material

## Responsable

Juan Manuel Beltrán Botello · [@JuanBeltran2024](https://github.com/JuanBeltran2024)



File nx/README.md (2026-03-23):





# nx — Siemens NX / Modelado CAD



Modelos 3D de la línea de producción y simulaciones cinemáticas en Siemens NX. Incluye la exportación de puntos desde RobotStudio a NX para integración con el gemelo digital.

## Contenido esperado

- `modelos-3d/` — Ensamblajes y piezas de la línea (.prt)
- `simulaciones/` — Archivos de simulación de movimiento y flujo

## Responsables

| Rol | Nombre | GitHub |
|---|---|:---:|
| Desarrollador principal | Juan Manuel Beltrán Botello | [@JuanBeltran2024](https://github.com/JuanBeltran2024) |
| **Supervisor NX/DF** | **Samuel David Sanchez Cardenas** | [@samsanchezcar](https://github.com/samsanchezcar) |



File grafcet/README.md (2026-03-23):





# grafcet — Lógica Secuencial



Diagramas Grafcet (SFC) del control lógico-secuencial de la línea, por producto y modo de operación.

## Contenido esperado

- `diagramas/` — Grafcet por producto, modos manual/automático, arranque y paro de emergencia

## Responsable

Juan José Díaz Guerrero · [@Judiazgu](https://github.com/Judiazgu)



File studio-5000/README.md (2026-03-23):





# studio-5000 — Allen-Bradley / Logix Emulate



Programas de control PLC desarrollados en Studio 5000, validados en Logix Emulate.

## Contenido esperado

- `programas/` — Archivos `.ACD` con la lógica de control completa
- `tags/` — Exportación de tags del controlador (`.CSV` / `.L5X`)

## Responsable

Juan José Díaz Guerrero · [@Judiazgu](https://github.com/Judiazgu)



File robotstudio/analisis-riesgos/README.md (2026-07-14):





# Evaluación de Riesgos



> Resumen del informe completo de identificación, estimación y reducción de riesgos de las dos celdas robóticas de paletizado, conforme a ISO 14121-1 e ISO 10218-1/2. El informe completo se encuentra en [APM_Safety](APM_Safety.pdf).

## Objetivo y alcance

El informe identifica, estima y reduce los riesgos asociados a la operación de las dos celdas robóticas de paletizado: la celda con manipulador articulado ABB IRB 5710 (garrafones de 25 L) y la celda con sistema gantry cartesiano XZ (cajones de 330 ml y paquetes PET de 1.5 L). Cubre desde la determinación de los límites de cada celda hasta la reducción de riesgo y el cálculo del riesgo residual, quedando fuera de alcance el PLC de línea (gestionado por terceros) y cualquier otra celda de la planta.

## Metodología

Se aplicó el método de matriz de riesgo (Probabilidad × Impacto, escala 1-5), con categorización en cuatro niveles: Bajo, Medio, Alto y Extremo.

<p align="center">
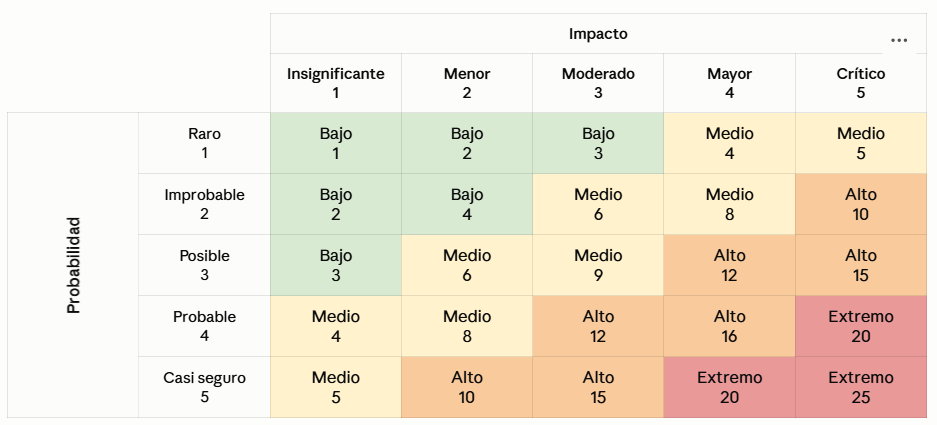
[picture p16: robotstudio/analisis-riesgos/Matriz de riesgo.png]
Matriz de riesgo
  
</p>

## 1. Identificación de peligros

Se identificaron **21 peligros** en total: 10 en la celda del manipulador (G01-G10) y 11 en la celda gantry (H01-H11), cubriendo las categorías mecánica, eléctrica, neumática, ergonómica, térmica y de entorno, distribuidos en las fases de operación automática, carga/descarga, mantenimiento, ajuste y limpieza.

Los peligros más representativos incluyen: impacto/aplastamiento por movimiento del equipo, atrapamiento en el punto de operación, caída de carga suspendida, contacto eléctrico, arranque inesperado durante mantenimiento, e ingreso de personal a la zona de riesgo durante el paso automático de material.

## 2. Estimación y valoración del riesgo

Aplicando la matriz de riesgo sin considerar medidas de protección (riesgo inicial), el resultado fue:

| Celda | Riesgo Alto | Riesgo Medio | Riesgo Extremo |
|---|---|---|---|
| Manipulador IRB 5710 | 7 de 10 | 3 de 10 | 0 |
| Gantry cartesiano | 8 de 11 | 3 de 11 | 0 |

Bajo el criterio de aceptación adoptado (Alto = no tolerable, requiere reducción; Medio = tolerable bajo ALARP), **14 de los 21 peligros identificados (67%) requirieron una medida de reducción de riesgo**.

## 3. Reducción de riesgo y riesgo residual

Se aplicó la jerarquía de control de ISO 12100/14121-1 (diseño intrínseco → protección técnica → información para el uso), mapeando cada peligro que requería reducción con el dispositivo o medida ya contemplada en el diseño de cada celda (vallado, interlocks, cortinas de luz con muting, válvulas de retención, protecciones eléctricas, entre otros).

**Medidas técnicas principales aplicadas:**
- Vallado perimetral + puerta con enclavamiento + cortinas de luz con muting → reduce los peligros de impacto/atrapamiento y de ingreso durante el paso de material en ambas celdas
- Válvulas de retención pilotada (gantry) y válvula anti-retorno en el generador de vacío (manipulador) → reduce el riesgo de caída de carga suspendida
- Breaker + RCD tipo B en ambos tableros → reduce el riesgo de contacto eléctrico
- Freno electromagnético del motor del eje Z → refuerza la retención de carga en el gantry

**Medidas administrativas y de información transversales:**
- Señalización de advertencia normalizada (puertas de acceso y zonas de muting)
- Procedimiento de bloqueo y etiquetado (LOTO) para mantenimiento y ajuste
- Programa de capacitación del personal operativo y de mantenimiento
- Equipo de protección personal (auditivo y ocular, según la tarea)

### Riesgos que permanecen sin reducir (pendientes)

- **Exposición a ruido (G08/H10)**: pendiente de medición sonométrica en operación para definir la necesidad y tipo de protección auditiva.

## Conclusión

El análisis muestra que ambas celdas comparten los mismos ejes críticos de riesgo pese a su arquitectura mecánica distinta, y que las medidas de protección ya contempladas en el diseño reducen la mayoría de los peligros de categoría Alto a Medio o Bajo.



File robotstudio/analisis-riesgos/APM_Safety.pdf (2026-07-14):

### Informe de Evaluación de Riesgos de las Celdas Robóticas de Paletizado — Sistema Gantry Cartesiano XZ y Manipulador Articulado ABB IRB 5710

### Andrés Felipe Quenan Pozo Juan José Diaz Guerrero Juan Manuel Beltran Botello Jorge Nicolas Garzón Acevedo Samuel David Sanchez Cardenas Juan Felipe Triana Aguilera Andrés Mauricio Morales Martínez

### PROFESORES Ricardo Emiro Ramírez Víctor Hugo Grisales Luis Miguel Méndez Carlos Julio Cortés Eduardo Barrera Gualdron Ubaldo García Zaragoza

### Universidad Nacional de Colombia Facultad de Ingeniería Departamento de Ingeniería Mecánica y Mecatrónica Bogotá D.C

2024

1. Generalidades

1.1 Objetivo

El presente informe tiene como objetivo identificar, estimar y valorar los riesgos asociados a la operación de las dos celdas robóticas de paletizado que conforman la línea de embotellado: la celda de paletizado con sistema gantry cartesiano de ejes X-Z (destinada a cajones de botellas retornables de 330 ml y paquetes termoformados PET de 1.5 litros) y la celda de paletizado con manipulador articulado ABB IRB 5710 (destinada a garrafones de 25 litros).
Este análisis busca proporcionar una base técnica documentada que permita determinar cuáles de los peligros identificados presentan un nivel de riesgo que requiere ser reducido mediante medidas de protección.

1.2 Alcance

El presente informe cubre el proceso de identificación, estimación y valoración de riesgos de ambas celdas robóticas, siguiendo los lineamientos de ISO 14121-1:2008 para la evaluación de riesgo de maquinaria, en conjunto con los requisitos aplicables de ISO 10218-1 e ISO 10218-2 para robots y sistemas robóticos industriales. El análisis comprende:

- La determinación de los límites de cada celda (uso previsto, mal uso razonablemente previsible, límites espaciales y temporales).
- La identificación sistemática de los peligros mecánicos, eléctricos, neumáticos, ergonómicos y de entorno presentes en cada fase operativa (operación automática, carga y descarga, mantenimiento, ajuste y limpieza).
- La estimación del nivel de riesgo inicial de cada peligro identificado, sin considerar las medidas de protección.
- La valoración de dicho riesgo frente al criterio de aceptación definido, determinando qué peligros requieren reducción de riesgo adicional.

1.3 Normativa de referencia

- ISO 14121-1:2008: Principios y metodología de evaluación de riesgo.
- ISO 10218-1:2011: Requisitos de seguridad del robot/eje motorizado como equipo
- ISO 10218-2:2011: Requisitos de integración del sistema robótico (perímetro, dispositivos de protección, distancias).
- ISO 13849-1:2015: Determinación del Nivel de Prestación requerido (PLr) de las funciones de seguridad identificadas
- ISO 13857:2019: Distancias de seguridad para impedir el acceso a zonas de peligro
- ISO 13855:2010: Posicionamiento de equipos de protección en función de la velocidad de aproximación del cuerpo humano
- ISO 3864-2:2016: Diseño de señales de seguridad y avisos de advertencia

2. Metodología

2.1 Determinación de límites de la maquinaria

2.1.1 Celda de paletizado — Sistema Gantry Cartesiano (Ejes X-Z)


Figura 2.1: Vista isométrica de celda de paletizado - Sistema Gantry Cartesiano

Límites de uso

Uso previsto:

- Paletizado automático alternado de capas de cajones retornables de 330 ml (9 cajones/capa) y capas de paquetes termoformados PET de 1.5 L (28 paquetes/capa), mediante gripper neumático de 4 mordazas.
- Desplazamiento en el eje X (5 m) y eje Z (2.3 m) para trasladar cada capa desde el punto de recolección hasta uno de los dos pallets de destino.
- Manipulación de cargas de hasta aproximadamente 260 kg por capa (caso más pesado, paquetes 1.5 L).

Mal uso razonablemente previsible:

- Ingreso a la zona de peligro a través de las bandas de infeed/outfeed en lugar de la puerta de acceso.
- Intervención manual sobre una capa retenida en el gripper sin despresurizar y purgar el circuito neumático.

- Permanencia bajo la trayectoria del eje X asumiendo que el carro ”normalmente no llega a ese punto”, sin verificación de posición segura (el sistema no cuenta con monitoreo de posición certificado en seguridad en los ejes externos).
- Mantenimiento del conjunto motor-husillo del eje Z sin soporte mecánico adicional ni bloqueo de energía, con riesgo de descenso incontrolado por gravedad.
- Anulación del muting o de una cortina de luz para acelerar el ciclo alternado de producto.

Límites de espaciales

- Envolvente de riesgo tipo prisma rectangular: todo el recorrido de 5 m del eje X, además de dimensiones adicionales por los soportes del gantry para un total de 5770 mm. Respecto al eje Y, abarca aproximadamente la dimensión del gripper y una distancia de seguridad para un total de 2250 mm. La envolvente de trabajo se encuentra proyectada en el suelo mediante el rectángulo marcado en amarillo, como se muestra en la figura 2.2.

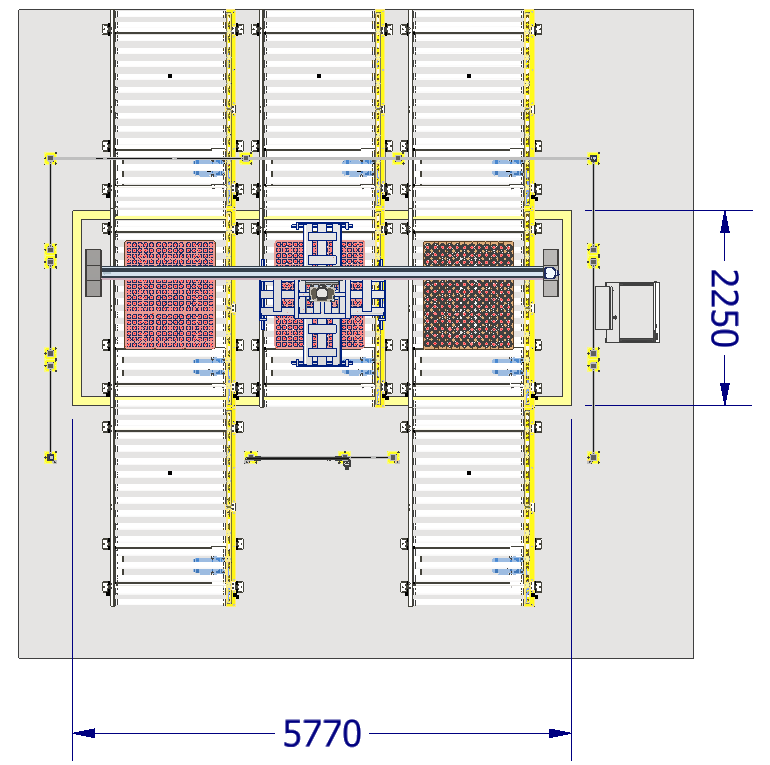
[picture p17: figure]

Figura 2.2: Vista de planta de celda de paletizado - Sistema Gantry Cartesiano

- Altura de riesgo relevante hasta aproximadamente 2.5 m (límite físico de alcance humano por encima de la cabeza); la porción superior de la estructura (hasta 4 m) queda fuera de esta consideración por ser inalcanzable.
- Dos puntos de interfaz con zonas colindantes: 2 outfeed, cada uno con cortina de luz y función de muting.

Límites temporales

- Vida útil de diseño de los componentes mecánicos (perfiles Bosch Rexroth, motores ABB MU200 y MU300) según especificación de fabricante.

- Operación en ciclo continuo con alternancia constante entre los dos tipos de producto.
- Frecuencia de mantenimiento preventivo del conjunto motor-reductor-husillo/correa de 2 meses sin sistema de lubricación automático y de 6 meses para componentes de movimiento.

2.1.2 Celda de paletizado — Manipulador ABB IRB 5710


Figura 2.3: Vista isométrica de celda de paletizado - Manipulador ABB IRB 5710

Límites de uso

Uso previsto:

- Paletizado automático de garrafones de 25 litros de agua, en ciclo continuo, con manipulación simultánea de 3 unidades por ciclo mediante gripper de vacío de 3 ventosas.
- Formación de pallets de 5 capas × 6 posiciones sobre rack.
- Operación predominante en modo automático; intervención humana limitada a cambio de pallet vacío, resolución de fallas menores y mantenimiento programado.

Mal uso razonablemente previsible:

- Ingreso a la zona de peligro a través de las bandas de infeed/outfeed en lugar de la puerta de acceso.
- Apertura de la puerta de acceso e intento de despejar un atasco sin aplicar el procedimiento de bloqueo de energía

- Anulación de un dispositivo de seguridad para reducir el tiempo de ciclo o resolver una falla recurrente.
- Permanencia dentro del vallado en modo manual sin activar el modo de velocidad/potencia reducida.
- Paletizado de garrafones con peso fuera de la especificación de diseño (superior a 25 L o con gripper cargado de forma incompleta/asimétrica).

Límites de espaciales

- Envolvente de riesgo definida por el alcance del robot (2.3 m) más la extensión del gripper y el garrafón en la postura más desfavorable para un total de 2920 mm. La envolvente de trabajo se encuentra proyectada en un circulo con centro en la base del robot y diámetro 6040 mm, como se muestra en la figura 2.4.

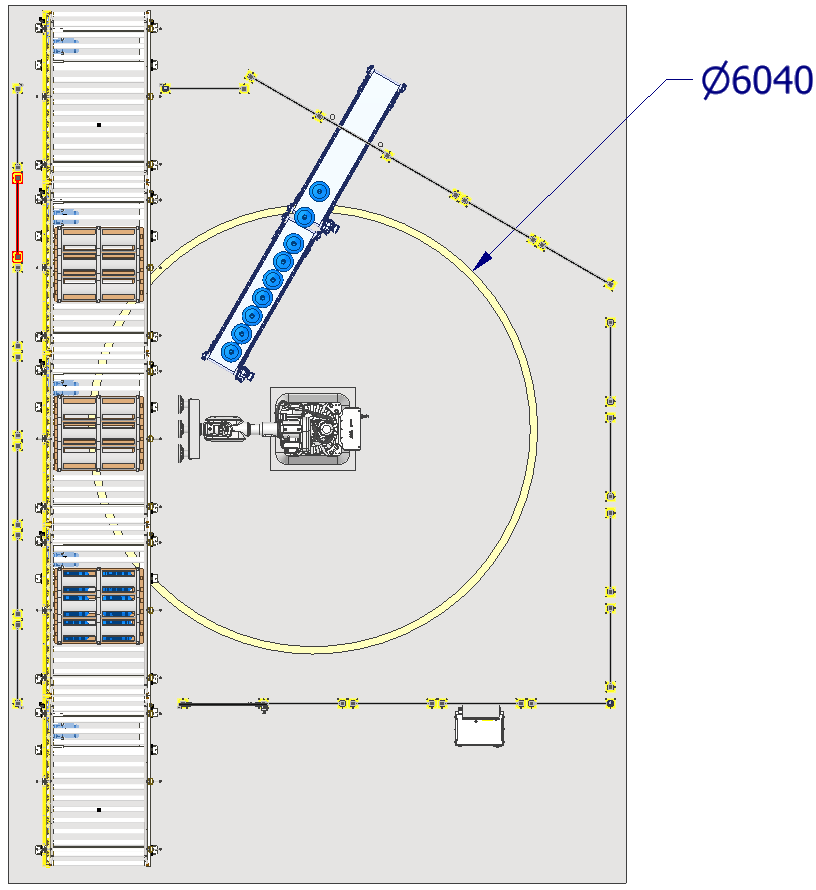
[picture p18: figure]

Figura 2.4: Vista planta de celda de paletizado - Manipulador ABB IRB 5710

- Perímetro delimitado por vallado modular con distancia de seguridad calculada conforme a ISO 13857.
- Puntos de interfaz con zonas colindantes: banda de infeed (garrafones), banda de outfeed (pallets), con cortina de luz y función de muting.

Límites temporales

- Vida útil de diseño del sistema robótico que es aproximadamente 10 años.

- Operación prevista en ciclo continuo durante los turnos de producción de la planta.
- Frecuencia de mantenimiento preventivo según programa del fabricante (ABB) para robot y controlador, aproximadamente cada 6 meses para mantenimiento preventivo.

2.2 Identificación de peligros

2.2.1 Celda de paletizado — Sistema Gantry Cartesiano

ID | Peligro | Tarea/Fase | Tipo (Anexo B)
H01 | Impacto o aplastamiento por
movimiento del carro en el eje X
(recorrido de 5 m).
Operación automática | Mecánico | (choque, | aplas-
tamiento).

H02 Atrapamiento en el mecanismo de las cuatro mordazas del gripper.

Operación y ajuste | Mecánico (atrapamiento, cizal-
lamiento).

H03 Caída de carga suspendida por falla de presión neumática durante el transporte.

Operación automática | Mecánico (caída de objeto).
H04 | Golpe contra pilares o estructura
fija del gantry.
Circulación general | Mecánico (golpe con parte fija).
H05 | Contacto eléctrico directo o in-
directo en tablero, controlador IRC5 o motores.
Mantenimiento eléctrico | Eléctrico.
H06 | Liberación inesperada de energía
neumática almacenada.
Mantenimiento | Neumático | (energía | almace-
| nada).
H07 | Arranque inesperado del gantry
durante mantenimiento o ajuste.
Mantenimiento | Mecánico / Eléctrico.
H08 | Ingreso de personal a la zona de
riesgo durante el movimiento automático del material.
Operación (infeed/outfeed) | Mecánico | (impacto, | atra-
| pamiento).
H09 | Proyección de fragmentos por
rotura de botella de vidrio dentro del cajón.
Operación automática | Otro (proyección de partículas).
H10 | Exposición a ruido generado por
cilindros neumáticos y motores.
Operación automática | Ruido.
H11 | Pérdida progresiva de fuerza de
sujeción del gripper por desgaste de las almohadillas de poliuretano.

Mantenimiento / Operación automática

Mecánico (pérdida de función de sujeción).

Tabla 2.1: Identificación de peligros de la celda de paletizado - Sistema gantry cartesiano

2.2.2 Celda de paletizado — Manipulador ABB IRB 5710

ID | Peligro | Tarea/Fase | Tipo (Anexo B)
G01 | Impacto o aplastamiento por
movimiento del brazo articulado
dentro de su envolvente de trabajo.
Operación automática | Mecánico | (choque, | aplas-
tamiento).

G02 Atrapamiento entre el brazo del robot y la estructura fija (rack o banda transportadora) durante la trayectoria.

Operación y ajuste | Mecánico (atrapamiento).
G03 | Caída de uno o varios garrafones
suspendidos por falla del sistema de vacío durante el transporte.
Operación automática | Mecánico (caída de objeto).
G04 | Contacto eléctrico directo o in-
directo en el tablero, controlador OmniCore o motores del robot.
Mantenimiento eléctrico | Eléctrico.
G05 | Liberación inesperada de energía
neumática almacenada en el circuito de vacío.
Mantenimiento | Neumático | (energía | almace-
| nada).
G06 | Arranque inesperado del robot
durante mantenimiento o ajuste.
Mantenimiento | Mecánico / Eléctrico.
G07 | Ingreso de personal a la zona
de riesgo durante el movimiento automático del material (infeed/outfeed).
Operación (muting) | Mecánico | (impacto, | atra-
| pamiento).
G08 | Exposición a ruido generado por
el robot y el gripper neumático durante la operación.
Operación automática | Ruido.
G09 | Posturas | forzadas | y | so-
breesfuerzo durante el reemplazo manual de las ventosas de vacío
| desgastadas.
Mantenimiento | Ergonómico.
G10 | Derrame de agua y riesgo de res-
balón por rotura de un garrafón
durante la manipulación.
Operación automática | Otro (fuga de líquido).

Tabla 2.2: Identificación de peligros de la celda de paletizado - Manipulador ABB IRB 5710

2.3 Estimación y Evaluación del Riesgo

La estimación y evaluación del riesgo de los peligros identificados se realiza mediante el método de matriz de riesgo, en el cual el nivel de riesgo se obtiene como el producto de dos variables: la probabilidad de ocurrencia del evento peligroso y el impacto (gravedad) del daño potencial asociado, expresado mediante la relación:
N ivel de Riesgo = P robabilidad × Impacto Cada variable se califica en una escala de 1 a 5, conforme a los descriptores definidos en las Tablas 2.3 y 2.4, y el producto resultante se ubica dentro de una matriz de 5×5 que clasifica el riesgo en cinco categorías: Bajo, Medio, Alto y Extremo, tal como se muestra en la matriz de referencia. Este método permite priorizar los peligros identificados según su nivel de riesgo relativo, y sirve como base objetiva para determinar, en la etapa de valoración, cuáles requieren la implementación de medidas de reducción de riesgo antes de la puesta en marcha de la celda, y cuáles pueden considerarse tolerables en su condición actual. El criterio de calificación de probabilidad e impacto, así como la matriz de riesgo empleada, se basan en el esquema de evaluación de riesgos de ISO/IEC 17025:2017, adaptado en este informe al contexto de seguridad de máquinas conforme a ISO 14121-1.
Nivel | Descriptor | Descripción
1 | Raro | Requiere el fallo simultáneo de varias barreras o circunstancias excepcionales poco realistas; no se espera que ocurra durante la vida útil del equipo.
2 | Improbable | Podría ocurrir en algún momento, pero no existe expectativa de que suceda durante la operación o el mantenimiento normal.
3 | Posible | Podría presentarse durante la vida útil del equipo bajo circunstancias particulares no rutinarias, por ejemplo, una intervención de mantenimiento sin el procedimiento adecuado.
4 | Probable | Se espera que ocurra en la mayoría de las circun- stancias, durante la operación normal o en tareas recurrentes de la celda.
5 | Casi seguro | Se espera que ocurra en casi todas las circun- stancias; la exposición al peligro es prácticamente constante o inevitable durante la ejecución de la tarea.

Tabla 2.3: Escala de probabilidad

Nivel | Descriptor | Descripción
1 | Insignificante | Sin lesión o con lesión que no requiere atención médica más allá de primeros auxilios menores.
2 | Menor | Lesión leve y reversible; incapacidad temporal corta (por ejemplo, contusión, esguince menor o molestia musculoesquelética).
3 | Moderado | Lesión que requiere atención médica significa- tiva e incapacidad temporal prolongada, pero re- versible.
4 | Mayor | Lesión grave, irreversible o permanente (fractura mayor, amputación o pérdida de la función de un miembro).
5 | Crítico | Lesión mortal o lesiones graves múltiples si- multáneas.

Tabla 2.4: Escala de impacto

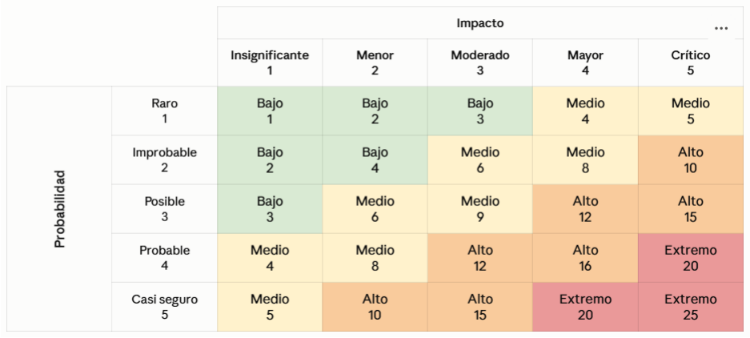
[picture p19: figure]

Figura 2.5: Matriz de riesgos

2.3.1 Celda de paletizado — Sistema Gantry Cartesiano

ID | Probabilidad | Impacto | Puntaje | Riesgo inicial
H01 | 4 – Probable | 4 – Mayor | 16 | Alto
H02 | 3 – Posible | 4 – Mayor | 12 | Alto
H03 | 3 – Posible | 5 – Crítico | 15 | Alto
H04 | 3 – Posible | 2 – Menor | 6 | Medio
H05 | 3 – Posible | 5 – Crítico | 15 | Alto
H06 | 3 – Posible | 4 – Mayor | 12 | Alto
H07 | 3 – Posible | 5 – Crítico | 15 | Alto
H08 | 4 – Probable | 4 – Mayor | 16 | Alto
H09 | 3 – Posible | 2 – Menor | 6 | Medio
H10 | 5 – Casi seguro | 2 – Menor | 10 | Alto
H11 | 3 – Posible | 3 – Moderado | 9 | Medio

Tabla 2.5: Estimación del riesgo inicial — Celda de paletizado con sistema gantry cartesiano

2.3.2 Celda de paletizado — Manipulador ABB IRB 5710

ID | Probabilidad | Impacto | Puntaje | Riesgo inicial
G01 4 – Probable | 4 – Mayor | 16 | Alto
G02 3 – Posible | 4 – Mayor | 12 | Alto
G03 2 – Improbable | 3 – Moderado | 6 | Medio
G04 3 – Posible | 5 – Crítico | 15 | Alto
G05 3 – Posible | 3 – Moderado | 9 | Medio
G06 3 – Posible | 5 – Crítico | 15 | Alto
G07 4 – Probable | 4 – Mayor | 16 | Alto
G08 5 – Casi seguro | 2 – Menor | 10 | Alto
G09 3 – Posible | 2 – Menor | 6 | Medio
G10 3 – Posible | 2 – Menor | 6 | Medio

Tabla 2.6: Estimación del riesgo - Celda de paletizado con manipulador ABB IRB 5710

2.4 Valoración del riesgo

El criterio de aceptación adoptado en este informe se basa en las cuatro categorías de la matriz de riesgo (Bajo, Medio, Alto, Extremo), asociando a cada una una decisión de valoración conforme al principio ALARP (As Low As Reasonably Practicable).

2.4.1 Criterio de aceptación

Nivel de riesgo | Rango | Decisión de valoración
Bajo | 1–4 | Tolerable. No se requiere acción adicional inmediata.
Medio | 5–9 | Tolerable bajo el principio ALARP. Se recomienda evaluar mejoras si son razonablemente viables, sin que sean condición para la puesta en marcha.
Alto | 10–16 | No tolerable. Requiere la implementación de medidas de reducción del riesgo antes de la puesta en marcha de la celda.
Extremo | 20–25 | Inaceptable. Requiere una reducción inmediata y prioritaria del riesgo; la operación no debe iniciar mientras el riesgo permanezca en este nivel.

Tabla 2.7: Criterio de aceptación del riesgo

2.4.2 Valoración — Celda de paletizado con sistema gantry cartesiano

ID | Riesgo inicial | ¿Requiere reducción del riesgo?
H01 | Alto (16) | Sí.
H02 | Alto (12) | Sí.
H03 | Alto (15) | Sí.
H04 | Medio (6) | No. Tolerable bajo el principio ALARP.
H05 | Alto (15) | Sí.
H06 | Alto (12) | Sí.
H07 | Alto (15) | Sí.
H08 | Alto (16) | Sí.
H09 | Medio (6) | No. Tolerable bajo el principio ALARP.
H10 | Alto (10) | Sí.
H11 | Medio (9) | No. Tolerable bajo el principio ALARP.

Tabla 2.8: Valoración del riesgo de la celda de paletizado con sistema gantry cartesiano

2.4.3 Valoración — Celda de paletizado con manipulador ABB IRB 5710

ID | Riesgo inicial | ¿Requiere reducción del riesgo?
G01 | Alto (16) | Sí.
G02 | Alto (12) | Sí.
G03 | Medio (6) | No. Tolerable bajo el principio ALARP.
G04 | Alto (15) | Sí.
G05 | Medio (9) | No. Tolerable bajo el principio ALARP.
G06 | Alto (15) | Sí.
G07 | Alto (16) | Sí.
G08 | Alto (10) | Sí.
G09 | Medio (6) | No. Tolerable bajo el principio ALARP.
G10 | Medio (6) | No. Tolerable bajo el principio ALARP.

Tabla 2.9: Valoración del riesgo de la celda de paletizado con manipulador ABB IRB 5710

2.5 Reducción de riesgo y riesgo residual

Se identifica la medida de reducción de riesgo correspondiente, siguiendo la jerarquía de control de ISO 12100/14121-1: eliminación o diseño intrínsecamente seguro, protección técnica (resguardos, enclavamientos, dispositivos de detección), e información/procedimientos para el usuario.

2.5.1 Sistema Gantry Cartesiano

ID | Riesgo inicial | Riesgo residual | Observación
H01 | Alto (16) | Medio (4) | Vallado perimetral, puerta con enclavamiento AZM 415 y cortinas fotoeléctricas con función de muting.
H02 | Alto (12) | Medio (4) | Contención dentro del vallado y procedimiento de blo-queo y etiquetado (LOTO).
H03 | Alto (15) | Medio (5) | Válvulas HGL y freno MU300.
H04 | Medio (6) | Medio (6) | Sin medida técnica adicional; únicamente se re-comienda señalización.
H05 | Alto (15) | Medio (5) | Interruptor ABB S203-K25, RCD tipo B F204B y gabi-nete con grado de protección IP66.
H06 | Alto (12) | Medio (8) | Reducción parcial; pendiente instalar válvula de blo-queo con purga visible.
H07 | Alto (15) | Medio (5) | Técnica (relé/PLC de seguridad).
H08 | Alto (16) | Medio (4) | Cortinas fotoeléctricas AD 1651, controlador SR ONE M y sensores Pepperl+Fuchs.
H09 | Medio (6) | Medio (6) | Sin medida técnica adicional; pendiente implementar controles administrativos.
H10 | Alto (10) | Medio (6) | Administrativa (Nivel 3 — EPP auditivo + capac-itación, no elimina la fuente de ruido).
H11 | Alto (12) | Medio (8) | Reducción parcial mediante regulador VPPM; falta es-tablecer inspecciones periódicas.

Tabla 2.10: Reducción del riesgo - celda de paletizado con sistema gantry cartesiano

2.5.2 Manipulador ABB IRB 5710

ID | Riesgo inicial | Riesgo residual | Observación
G01 | Alto (16) | Medio (4) | Vallado perimetral, puerta con enclavamiento AZM 415 y cortinas fotoeléctricas con función de muting.
G02 | Alto (12) | Medio (4) | Contención dentro del vallado y procedimiento de blo-queo y etiquetado (LOTO).
G03 | Medio (6) | Bajo (3) | Válvula antirretorno integrada en el generador de vacío OVEM.
G04 | Alto (15) | Medio (5) | Interruptor ABB S203-K32, RCD tipo B F204B y gabi-nete con grado de protección IP66.
G05 | Medio (9) | Medio (6) | Reducción parcial; pendiente instalar una válvula de bloqueo con purga visible.
G06 | Alto (15) | Medio (5) | Técnica (relé/PLC de seguridad).
G07 | Alto (16) | Medio (4) | Cortinas fotoeléctricas AD 1501 e interfaz de seguridad SR ONE M con función de muting.
G08 | Alto (10) | Medio (6) | Administrativa (Nivel 3 — EPP auditivo + capac-itación, no elimina la fuente de ruido).
G09 | Medio (6) | Medio (6) | Sin medida técnica adicional; pendiente implementar controles administrativos.
G10 | Medio (6) | Medio (6) | Sin medida de reducción contemplada en el diseño ac-tual.

Tabla 2.11: Reducción del riesgo y riesgo residual de la celda de paletizado con manipulador ABB IRB 5710

2.6 Medidas Administrativas y de Información Transversales

Además de las medidas técnicas señaladas anteriormente, se identifican las siguientes medidas de información para el uso (Nivel 3 de la jerarquía de reducción de riesgo) que aplican de forma transversal a múltiples peligros en ambas celdas:

- Señalización de advertencia normalizada (ISO 3864-2): aviso tipo ”Peligro” en puertas de acceso de ambas celdas; aviso tipo ”Atención” en las zonas de muting de infeed/outfeed — asociadas a G07/H08.
- Procedimiento de bloqueo y etiquetado (LOTO): documentado y de cumplimiento obligatorio antes de cualquier intervención de mantenimiento o ajuste — respalda la reducción de riesgo de G02, G05, G06, H02, H06 y H07.
- Programa de capacitación del personal operativo y de mantenimiento: en el uso correcto de los dispositivos de seguridad (cortinas, interlock, paros de emergencia), en el procedimiento LOTO, y en el reconocimiento de las zonas de muting — respalda de forma general la efectividad de todas las medidas técnicas anteriores, dado que un resguardo o interlock mal utilizado por desconocimiento reduce su eficacia real.
- Equipo de protección personal (EPP): protección auditiva (asociada a G08/H10) y protección ocular para tareas de inspección/limpieza de cajones (asociada a G10).

3. Conclusiones

De los 21 peligros identificados entre las dos celdas (10 en la celda del manipulador ABB IRB 5710 y 11 en la celda del sistema gantry cartesiano), la aplicación de la matriz de riesgo probabilidad × impacto arrojó que 14 peligros se ubican en la categoría de riesgo Alto y 7 en la categoría Medio, sin que ningún peligro alcanzara la categoría Extremo.

Se observa un patrón consistente entre ambas celdas: los peligros de mayor puntaje corresponden, en ambos casos, a mecanismos estructuralmente equivalentes —impacto/aplastamiento por el movimiento principal del equipo (G01/H01), contacto eléctrico en tablero y controlador (G04/H05), arranque inesperado durante mantenimiento (G06/H07), e ingreso de personal durante el paso automático de material (G07/H08)—, lo cual sugiere que ambas celdas comparten los mismos ejes críticos de riesgo pese a tratarse de arquitecturas mecánicas distintas (manipulador articulado vs. sistema cartesiano).

La proporción mayoritaria de peligros en categoría Alto (14 de 21, equivalente al 67%) indica que ambas celdas presentan un nivel de riesgo global que no es aceptable para su operación para lo cual se implementaron medidas de seguridad mediante elementos que mitigan cada tipo de peligro.

Bibliography

[1] International Organization for Standardization, ISO 14121-1:2008 — Safety of machinery — Risk assessment — Part 1: Principles, Geneva, Switzerland, 2008.
[2] International Organization for Standardization, ISO 10218-1:2011 — Robots and robotic devices — Safety requirements for industrial robots — Part 1: Robots, Geneva, Switzerland, 2011.
[3] International Organization for Standardization, ISO 10218-2:2011 — Robots and robotic devices — Safety requirements for industrial robots — Part 2: Robot systems and integration, Geneva, Switzerland, 2011.
[4] International Organization for Standardization, ISO 13849-1:2015 — Safety of machinery — Safety-related parts of control systems — Part 1: General principles for design, Geneva, Switzerland, 2015.
[5] International Organization for Standardization, ISO 13857:2019 — Safety of machinery — Safety distances to prevent hazard zones being reached by upper and lower limbs, Geneva, Switzerland, 2019.
[6] International Organization for Standardization, ISO 13855:2010 — Safety of machinery — Positioning of safeguards with respect to the approach speeds of parts of the human body, Geneva, Switzerland, 2010.
[7] International Organization for Standardization, ISO 3864-2:2016 — Graphical symbols — Safety colours and safety signs — Part 2: Design principles for product safety labels, Geneva, Switzerland, 2016.
[8] International Organization for Standardization, ISO/IEC 17025:2017 — General requirements for the competence of testing and calibration laboratories, Geneva, Switzerland, 2017.

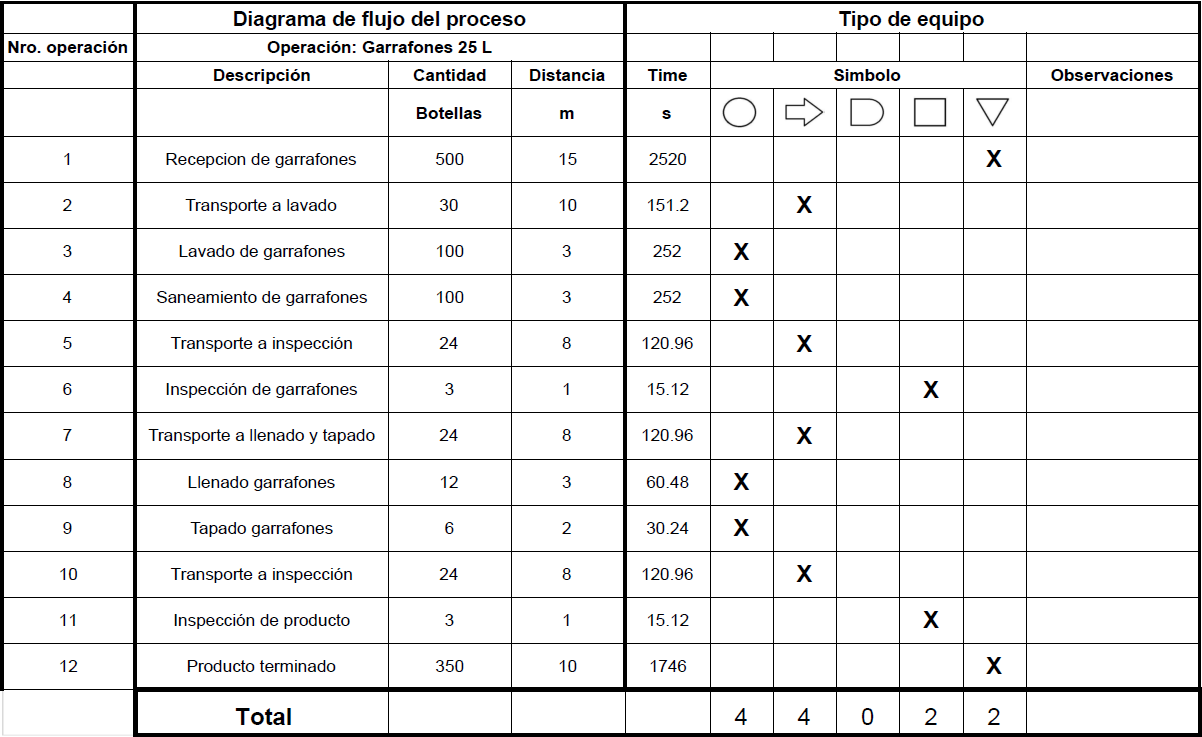
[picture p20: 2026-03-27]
proceso/diagramas/Diagrama_DAP_3_(Light).png

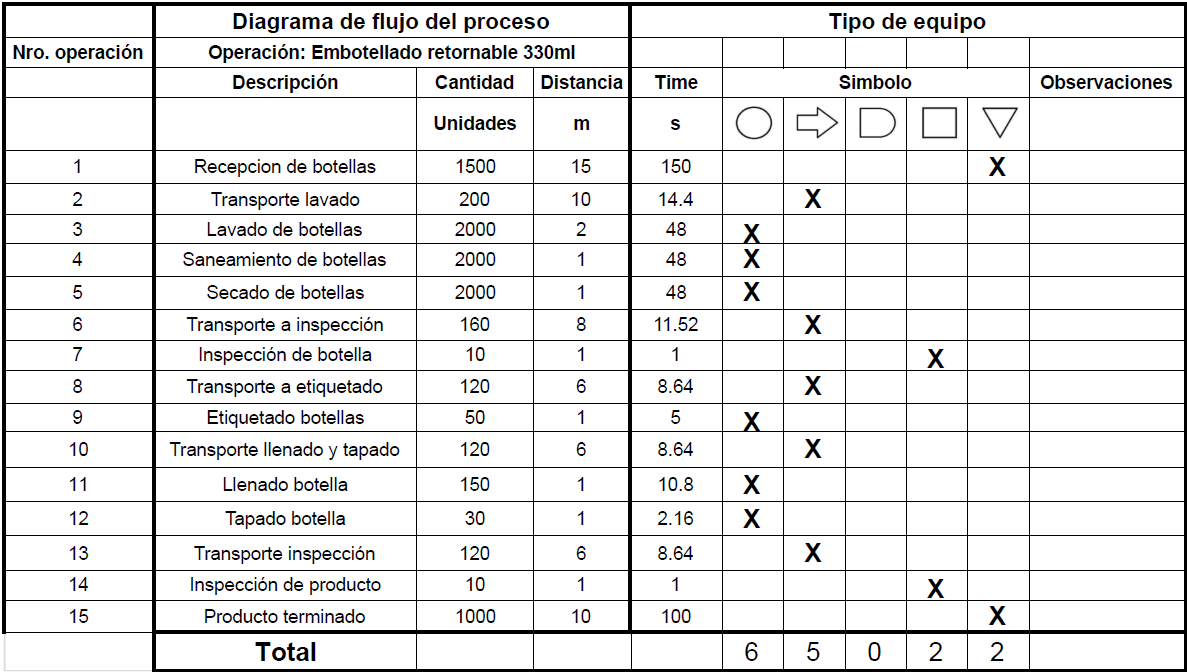
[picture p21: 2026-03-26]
proceso/diagramas/Diagrama_DAP_1_(Light).png

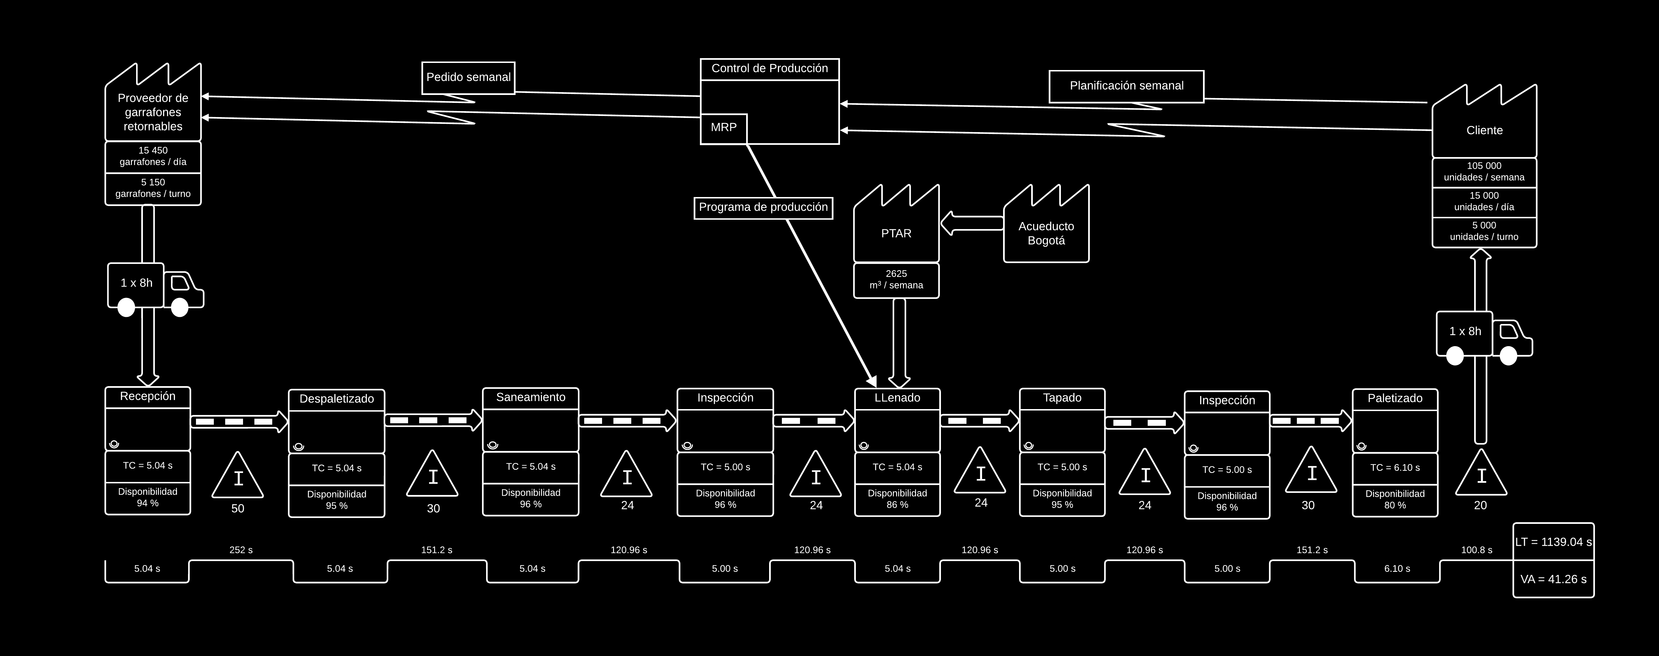
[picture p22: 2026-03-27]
proceso/vsm/Diagrama_VSM_3_(Dark).png

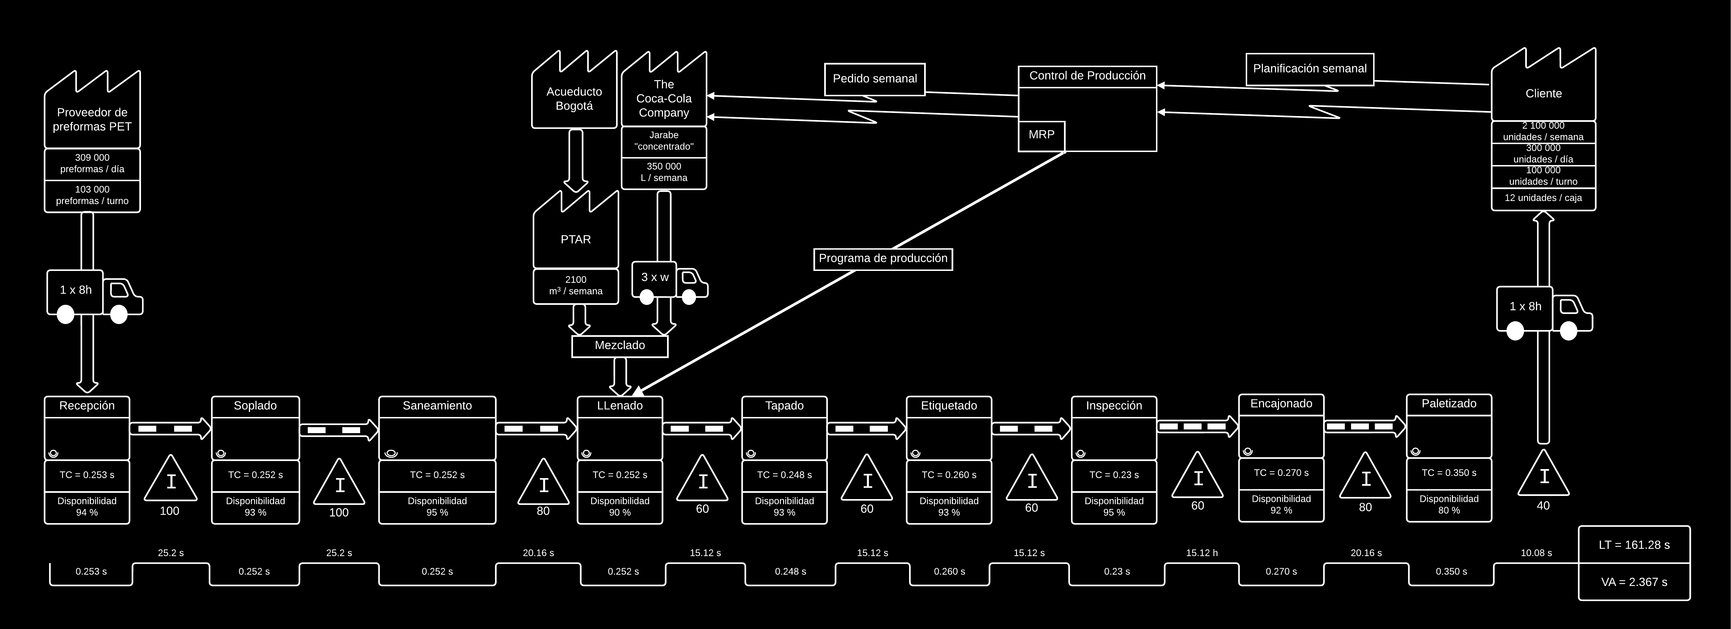
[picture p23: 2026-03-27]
proceso/vsm/Diagrama_VSM_2_(Dark).png

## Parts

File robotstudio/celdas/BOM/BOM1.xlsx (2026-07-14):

CELDA DE PALETIZADO - LÍNEA 1 - LÍNEA 2
Item | Categoría | Elemento | Descripción | Fabricante | Referencia | Especificaciones | Cantidad | Precio unitario estimado (USD) | Precio total estimado (USD)
1 | Robótica | Servomotor | Unidad motora compatible con controlador ABB para eje Z | ABB | MU 300 | Torque (Nm): 12 a 3000 rpm Velocidad nominal (rpm): 5000 | 1 | 2800 | 2800
2 | Robótica | Servomotor | Unidad motora compatible con controlador ABB para eje X | ABB | MU 200 | Torque (Nm): 6 a 2000 rpm Velocidad nominal (rpm): 5000 | 1 | 2000 | 2000
3 | Robótica | Controlador | Controlador diseñado para robots articulados y ejes externos | ABB | IRC5 | Voltaje de alimentación (V): 200-600 | 1 | 18000 | 18000
4 | Robótica | Reductor | Caja reductora de engranajes planetaria para motor MU 200 | Apex Dynamics | AB115-005-S2-P2 | Relación: 5:1 Torque de salida (Nm): 330 | 1 | 1100 | 1100
5 | Robótica | Eje lineal | Módulo compacto con ensamblaje de husillo de bolas 40x10 para eje Z | Bosch - Rexroth | Rexroth_CKK280_S2200 | Tamaño: 280 Carrera máxima: 2200 mm | 1 | 5500 | 5500
6 | Robótica | Eje lineal | Módulo compacto con transmisión por correa dentada para eje Z | Bosch - Rexroth | Rexroth_CKR280_S4600 | Tamaño: 280 Carrera máxima: 4600 mm | 1 | 7500 | 7500
7 | Robótica | Acople | Acople para el carro del eje X con el carro del eje Z | Manufacturado | ACP001 | Material: Acero SAE 1020 Masa: 20 kg | 1 | 450 | 450
8 | Soporte | Perfil | Perfil cuadrado en acero estructural para soporte del gantry | Manufacturado | SP001 | Material: Acero SAE 1020 Masa: 200 kg | 2 | 1200 | 2400
9 | Gripper | Gripper neumático | Estructura de gripper de 4 mordazas neumáticas | Manufacturado | GRP001 | Material: Aluminio 6061- T6 Masa: 40 kg | 1 | 9000 | 9000
10 | Neumática | Cilindro neumático | Cilindro perfilado con amortiguación neumática autorregulable | Festo | DSBC-80-150-PPSA-N3 | Carrera: 150 mm Diámetro de émbolo: 80 mm | 8 | 220 | 1760
11 | Neumática | Válvula de antirretorno | Válvula de retención pilotada que mantiene la retracción incluso sin suministro de aire | Festo | HGL-3/8-QS-8 | Presión de funcionamiento: 0.5-10 bar Conexión: G3/8 | 8 | 55 | 440
12 | Neumática | Electroválvula | Electroválvula direccional 5/2, biestable | Festo | VUVS-L30-B52-D-G38-F8-1B2 | Voltaje de funcionamiento: 24 VDC Conexión: G3/9 | 1 | 220 | 220
13 | Neumática | Regulador de caudal | Función de estrangulación y antirretorno del aire de escape | Festo | GRLA-3/8-QS-8-D | Caudal nominal: 820 l/min | 8 | 28 | 224
14 | Neumática | Sensor de posición | Transmisor de posición adecuado para ranura tipo T | Festo | SMAT-8M-U-E-2,5-OE | Caudal nominal: 820 l/min | 4 | 60 | 240
15 | Neumática | Unidad FRL | Unidad de filtro y regulador con margen de regulación de presión 0.3 bar - 7 bar | Festo | MS4-LFR-1/4-D6-E-R-M | Conexión neumática: G1/4 Caudal nominal normal: 1800 l/min | 1 | 240 | 240
16 | Transporte | Transportador | Transportador de rodillos con motor reductor | Interroll | PM 9710 | Capacidad de carga (kg): 1500 Voltaje de funcionamiento (V): 400 V | 8 | 5500 | 44000
17 | Detección | Sensor de posición | Sensor óptico de barrera por reflexión con filtro polarizado | Pepper+Fuchs | OBR7500-R100-2EP-IO-V31 | Voltaje de funcionamiento: 24 VDC Protección IP69K | 3 | 220 | 660
18 | Seguridad | Vallado modular | Mostrar más | Satech | ImpactGuard System-H3120-S60-T30 | Absorción de impacto de hasta 2200 J Malla: 20 x 100 mm | 6 | 220 | 1320
19 | Seguridad | Panel | Panel de protección perimetral contra altos impactos | Satech | Framed Panel - W 300 - H 2960 | Absorción de impacto de hasta 2200 J Malla: 20 x 100 mm Dimensiones: 300 x 2960 mm | 5 | 420 | 2100
20 | Seguridad | Panel | Panel de protección perimetral contra altos impactos | Satech | Framed Panel - W 200 - H 2960 | Absorción de impacto de hasta 2200 J Malla: 20 x 100 mm Dimensiones: 200 x 2960 mm | 1 | 380 | 380
21 | Seguridad | Panel | Panel de protección perimetral contra altos impactos | Satech | Framed Panel - W 700 - H 1480 | Absorción de impacto de hasta 2200 J Malla: 20 x 100 mm Dimensiones: 700 x 1480 mm | 1 | 220 | 220
22 | Seguridad | Panel | Panel de protección perimetral contra altos impactos | Satech | Framed Panel - W 800 - H 1480 | Absorción de impacto de hasta 2200 J Malla: 20 x 100 mm Dimensiones: 800 x 1480 mm | 4 | 240 | 960
23 | Seguridad | Panel | Panel de protección perimetral contra altos impactos | Satech | Framed Panel - W 1000 - H 1480 | Absorción de impacto de hasta 2200 J Malla: 20 x 100 mm Dimensiones: 1000 x 1480 mm | 1 | 260 | 260
24 | Seguridad | Puerta | Puerta sencilla para paso de personas, equipada con bisagras que guían el movimiento del panel. | Satech | Single Leaf Door ImpactGuard-H3120-S60-T30 | Absorción de impacto de hasta 2200 J Malla: 20 x 100 mm | 1 | 750 | 750
25 | Seguridad | Interlock | Dispositivo conectado al sistema de control. Cuando está abierto, impide que la máquina funcione. | Satech/Schmerzal | AZM 415-02/02ZPK 24VAC/DC | Retención regulable hasta 400 N | 1 | 320 | 320
26 | Seguridad | Cortina óptica | Cortina óptica de seguridad con detección de dedos y reinicio automático | ReeR | ADMIRAL AD 1651 | Nivel de seguridad: Tipo 4 - PL e Resolución: 14 mm | 2 | 1100 | 2200
27 | Seguridad | Interfaz de cortina óptica | Interfaz de seguridad para cortinas fotoeléctricas con función de silenciamiento | ReeR | SR ONE M | Nivel de seguridad: Tipo 4 - PL e Salidas de relé: 2 NO (6A a 250 VCA) | 2 | 380 | 760
28 | Seguridad | Torre de señalización | Torre de señalización preconfigurada en rojo/amarillo/verde. | Werma | KS72 Classic RM 24 VCA/CC GN/YE/RD | Tensión de funcionamiento: 24V | 2 | 210 | 420
29 | Seguridad | Parada de emergencia | Pulsador de parada de emergencia serie 45 | EAO | Serie 45-Ø 40 mm- 2NC | Capacidad de conmutación: 500 V AC @ 10 A | 1 | 35 | 35
30 | Seguridad | Parada de emergencia | Smart-Box de parada de emergencia, Serie 84 | EAO | Serie 84-Ø 32 mm-IP67-M12 | Capacidad de conmutación: 250 V | 1 | 70 | 70
31 | Protección de circuito | Breaker termomagnético | Para protección de circuito de potencia | ABB | S203-K25 | Número de polos: 3P Corriente nominal: 25 A | 1 | 70 | 70
32 | Protección de circuito | RCD | Interruptor automático de corriente residual | ABB | F204 B-40/0.3 | Número de polos: 4 Tensión de dimensionamiento: 400V Corriente nominal (medida): 40A | 1 | 350 | 350
33 | Protección de circuito | Mini-breaker 1P 1A | Interruptor magnetotérmico | ABB | S201-C1 | Poder de corte a 400 V: 10kA | 8 | 18 | 144
34 | Protección de circuito | Gabinete eléctrico | Spacial CRN con puerta ciega sin placa de montaje | Schneider Electric | NSYCRN75250 | 700x500x200 mm IP66 | 1 | 260 | 260
35 | Alimentación de circuito | Fuente de alimentación DC | Fuente de alimentación para componentes de seguridad y sensores | ABB | CP-E 24/10.0 | Valor nominal tensión de salida:24V Valor nominal corriente de salida:10A | 1 | 190 | 190
36 | Supervisión | HMI | Panel de control con pantalla táctil TFT de 4,3" | ABB | CP620 | 480 x 272 píxeles Licencia de ejecución PB610. | 1 | 650 | 650
 |  |  |  |  |  |  |  | TOTAL | 107993

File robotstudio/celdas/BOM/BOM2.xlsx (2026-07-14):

CELDA DE PALETIZADO - LÍNEA 3
Item | Categoría | Elemento | Descripción | Fabricante | Referencia | Especificaciones | Cantidad | Precio unitario estimado (USD) | Precio total estimado (USD)
1 | Robótica | Robot | Robot articulado industrial de 6 ejes con alto rendimiento y precisión | ABB | IRB 5710-110/2.3 | Alcance (m): 2,3 Carga útil (kg): 110 | 1 | 65000 | 65000
2 | Robótica | Controlador | Controlador diseñado para robots articulados de cargas de hasta 310 kg | ABB | Omnicore V250XT | Compatible hasta IRB 6790 | 1 | 22000 | 22000
3 | Transporte | Transportador | Transportador de rodillos con motor reductor | Interroll | PM 9710 | Capacidad de carga (kg): 1500 Voltaje de funcionamiento (V): 400 V | 5 | 5500 | 27500
4 | Gripper | Gripper neumático | Gripper neumático con 3 ventosas | Manufacturado | GRP001 | Material: Aluminio 6061-T6 Masa: 15.5 kg | 1 | 4500 | 4500
5 | Neumática | Generador de vacío | Gran volumen de aspiración con impulso de eyección | Festo | OVEM-14-L-B-QO-CE-N-1P | Caudal: 50 l/min - 3.6 bar Conexión eléctrica: M12 Sensor de vacío | 3 | 320 | 960
6 | Neumática | Acumulador de vacío | Acumulador de aire comprimido en acero inoxidable de alta aleación | Festo | CRVZS-0.1 | Volumen: 0.1 l | 3 | 45 | 135
7 | Neumática | Filtro de vacío | Filtro de vacío de malla y material de cuerpo PA | Festo | VAF-PK-6 | Grado de filtración: 50 μm | 3 | 55 | 165
8 | Neumática | Unidad FRL | Unidad de filtro y regulador con margen de regulación de presión 0.3 bar - 7 bar | Festo | MS4-LFR-1/4-D6-C-P-M-AG-BAR-B | Conexión neumática: G1/4 Caudal nominal normal: 1500 l/min | 1 | 220 | 220
9 | Seguridad | Vallado modular | Sistema de proteccion perimetral contra altos impactos | Satech | ImpactGuard System-H3120-S60-T30 | Absorción de impacto de hasta 2200 J Malla: 20 x 100 mm | 20 | 220 | 4400
10 | Seguridad | Puerta | Puerta sencilla para paso de personas, equipada con bisagras que guían el movimiento del panel. | Satech | Single Leaf Door ImpactGuard-H3120-S60-T30 | Absorción de impacto de hasta 2200 J Malla: 20 x 100 mm | 1 | 750 | 750
11 | Seguridad | Interlock | Dispositivo conectado al sistema de control. Cuando está abierto, impide que la máquina funcione. | Satech/Schmerzal | AZM 415-02/02ZPK 24VAC/DC | Retención regulable hasta 400 N | 1 | 320 | 320
12 | Seguridad | Cortina óptica | Cortina óptica de seguridad con detección de dedos y reinicio automático | ReeR | ADMIRAL AD 1651 | Nivel de seguridad: Tipo 4 - PL e Resolución: 14 mm | 2 | 1100 | 2200
13 | Seguridad | Cortina óptica | Control de Acceso Rejilla Luminosa de Seguridad con Reinicio Automático | ReeR | ADMIRAL AD 2B | Nivel de seguridad: Tipo 4 - PL e Resolución: Multi-haz | 1 | 550 | 550
14 | Seguridad | Interfaz de cortina óptica | Interfaz de seguridad para cortinas fotoeléctricas con función de silenciamiento | ReeR | SR ONE M | Nivel de seguridad: Tipo 4 - PL e Salidas de relé: 2 NO (6A a 250 VCA) | 2 | 380 | 760
15 | Seguridad | Interfaz de cortina óptica | Interfaz de seguridad para cortinas fotoeléctricas | ReeR | SR ONE | Nivel de seguridad: Tipo 4 - PL e Salidas de relé: 2 NO (6A a 250 VCA) | 1 | 260 | 260
16 | Seguridad | Torre de señalización | Torre de señalización preconfigurada en rojo/amarillo/verde. | Werma | KS72 Classic RM 24 VCA/CC GN/YE/RD | Tensión de funcionamiento: 24V | 2 | 210 | 420
17 | Seguridad | Parada de emergencia | Pulsador de parada de emergencia serie 45 | EAO | Serie 45-Ø 40 mm- 2NC | Capacidad de conmutación: 500 V AC @ 10 A | 1 | 35 | 35
18 | Seguridad | Parada de emergencia | Smart-Box de parada de emergencia, Serie 84 | EAO | Serie 84-Ø 32 mm-IP67-M12 | Capacidad de conmutación: 250 V | 1 | 70 | 70
19 | Protección de circuito | Breaker termomagnético | Para protección de circuito de potencia | ABB | S203-K32 | Número de polos: 3P Corriente nominal: 32 A | 1 | 75 | 75
20 | Protección de circuito | RCD | Interruptor automático de corriente residual | ABB | F204 B-40/0.3 | Número de polos: 4 Tensión de dimensionamiento: 400V Corriente nominal (medida): 40A | 1 | 350 | 350
21 | Protección de circuito | Mini-breaker 1P 1A | Interruptor magnetotérmico | ABB | S201-C1 | Poder de corte a 400 V: 10kA | 7 | 18 | 126
22 | Protección de circuito | Gabinete eléctrico | Spacial CRN con puerta ciega sin placa de montaje | Schneider Electric | NSYCRN75250 | 700x500x200 mm IP66 | 1 | 260 | 260
23 | Alimentación de circuito | Fuente de alimentación DC | Fuente de alimentación para componentes de seguridad y sensores | ABB | CP-E 24/10.0 | Valor nominal tensión de salida:24V Valor nominal corriente de salida:10A | 1 | 190 | 190
24 | Supervisión | HMI | Panel de control con pantalla táctil TFT de 4,3" | ABB | CP620 | 480 x 272 píxeles Licencia de ejecución PB610. | 1 | 650 | 650
 |  |  |  |  |  |  |  | TOTAL | 131896

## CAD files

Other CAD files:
nx/modelos-3d/Linea_1/Celda_1_2.stp
nx/modelos-3d/Linea_2/platificadora.step
nx/modelos-3d/Linea_3/Segurirdad_Linea_3.step
nx/modelos-3d/Linea_1/1330009_01.prt
nx/modelos-3d/Linea_1/1330009_011952677.prt
nx/modelos-3d/Linea_1/1330009_02.prt
nx/modelos-3d/Linea_1/1330009_021952678.prt
nx/modelos-3d/Linea_1/1330009_03.prt
nx/modelos-3d/Linea_1/1330009_031952679.prt
nx/modelos-3d/Linea_1/1330009_04.prt
nx/modelos-3d/Linea_1/1330009_041952680.prt
nx/modelos-3d/Linea_1/1330009_05.prt
nx/modelos-3d/Linea_1/1330009_051952681.prt
nx/modelos-3d/Linea_1/1330009_06.prt
nx/modelos-3d/Linea_1/1330009_061952682.prt
nx/modelos-3d/Linea_1/1330009_07.prt
nx/modelos-3d/Linea_1/1330009_071952683.prt
nx/modelos-3d/Linea_1/1330009_08.prt
nx/modelos-3d/Linea_1/1330009_081952684.prt
nx/modelos-3d/Linea_1/1330009_09.prt
nx/modelos-3d/Linea_1/1330009_091952685.prt
nx/modelos-3d/Linea_1/1330009_10.prt
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

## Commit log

2026-07-13 Update README with system and robot details
    Added detailed descriptions of the Cartesian Gantry System and ABB IRB 5710 Robot Manipulator, including specifications and safety features.
2026-07-13 Expand README with robotic system specifications
    Added detailed specifications for the robotic palletizing system, including mechanical structure, end effector, pneumatic system, material transport, electrical system, and safety measures.
2026-07-14 Update README with BOM links
    Added links to BOM1 and BOM2 in the README.
2026-07-14 Insert risk matrix image in README
    Added an image of the risk matrix to the README.
2026-07-23 Add Linea_1, Linea_2, Linea_3 models with LFS
    [01_PRODUCTO_step.prt, 02_TRANSPORTADOR_ENTRADA_step.prt, 03_DOSIFICADOR_step.prt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]
